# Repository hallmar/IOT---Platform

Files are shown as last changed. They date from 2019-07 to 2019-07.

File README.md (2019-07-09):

# Modular IOT Platform
Commissioned a modular IOT Platform for teaching purposes. There's a basic program in the 'Software' folder which is simply an IO test for the buttons and a test for the OLED.

Mouser Cart: https://www.mouser.com/ProjectManager/ProjectDetail.aspx?AccessID=9a8a02e45e

## Designed With

* Eagle CAD
* Arduino IDE

## Versioning
* 1.0 - [Hardware] Original hardware made
* 1.0 - [Software] Original 'basic' software written
## Authors

* **Hallmar Gauti Halldórsson**
* **Markus Pfeil**

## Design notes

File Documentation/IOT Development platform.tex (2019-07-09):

%TEMPLATE FILE
\documentclass{article}
\usepackage{graphicx} 
\usepackage{mathtools}
\usepackage{subcaption}
\usepackage[utf8x]{inputenc}
\usepackage{listings}
\usepackage{siunitx}
\usepackage{pdfpages}
\usepackage{pdflscape}
\usepackage{float}
\usepackage{xcolor}

\graphicspath{ {images/} }
\usepackage[obeyspaces]{url}
%\lstset{inputpath=C:/Users/Public/eclipse_workspace}
%\input{arduinoLanguage.tex}
\usepackage{color}   %May be necessary if you want to color links
\usepackage{hyperref}
\usepackage{titlesec}
\setcounter{secnumdepth}{4}

\hypersetup{
    colorlinks=true, % make the links colored
    linkcolor=blue, % color TOC links in blue
    urlcolor=red, % color URLs in red
    linktoc=all % 'all' will create links for everything in the TOC
    pdftitle={Sharelatex Example},
    bookmarks=true,
    pdfpagemode=FullScreen,
}
\hypersetup{
    colorlinks=true, % make the links colored
    linkcolor=blue, % color TOC links in blue
    urlcolor=blue, % color URLs in red
    linktoc=all % 'all' will create links for everything in the TOC
    pdftitle={Sharelatex Example},
    bookmarks=true,
    pdfpagemode=FullScreen,
    linkcolor=blue,
}

\definecolor{mGreen}{rgb}{0,0.6,0}
\definecolor{mGray}{rgb}{0.5,0.5,0.5}
\definecolor{mPurple}{rgb}{0.58,0,0.82}
\definecolor{backgroundColour}{rgb}{0.95,0.95,0.92}

\lstdefinestyle{CStyle}{
    %backgroundcolor=\color{backgroundColour},   
    commentstyle=\color{mGreen},
    keywordstyle=\color{magenta},
    numberstyle=\tiny\color{mGray},
    stringstyle=\color{mPurple},
    basicstyle=\footnotesize,
    breakatwhitespace=false,         
    breaklines=true,                 
    captionpos=b,                    
    keepspaces=true,                 
    numbers=left,                    
    numbersep=5pt,                  
    showspaces=false,                
    showstringspaces=false,
    showtabs=false,                  
    tabsize=2,
    language=C
}

\urlstyle{same}
\begin{document}
	\pagenumbering{gobble}
	\begin{titlepage}
		\centering
		\title{IOT Development platform \\ User manual \line(1,0){300}}
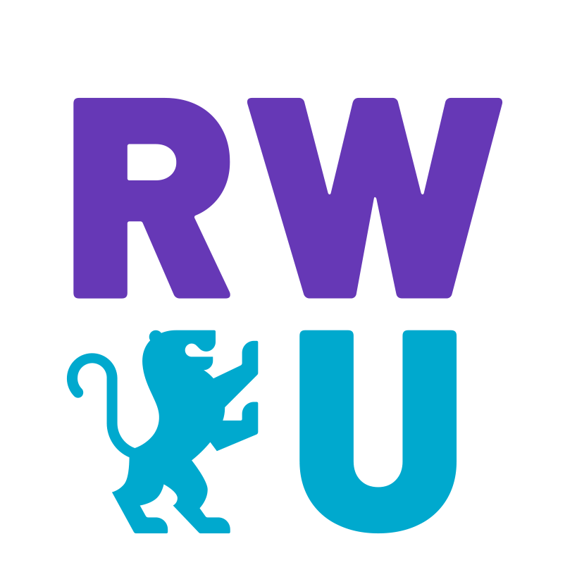
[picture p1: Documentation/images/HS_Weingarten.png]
		\date{25.06.2019 \\  \\  }
		\author{\Large Hallmar Gauti Halldórsson\\ {Matrikel: 29404} \\ 
		\\ \Large Ravensburg Weingarten Universität } %author og fleirri upplysinga
	\end{titlepage}
	\maketitle
	\newpage
	\tableofcontents
	\newpage
	\pagenumbering{arabic}

\section{Abstract}
This the documentation for an Open-Source IOT development platform that is modular in nature. It is built to have one essential part and two parts that are flexible in nature. The essential part is the Power Supply board which uses a 3.7V LIPO battery to power the whole system through a vertical pin bus. 
The Power supply board can also charge the battery and has a Buck-Boost converter to get an additional 5V voltage line out of the 3.3V voltage line that is already regulated. 
\newline\newline
Then as of now there is the Microcontroller board which has a Feather Wi-Fi development platform from Adafruit and a 2 row 90° angled header that functions as a breakout for all of the pins of the Microcontroller as well as the 5V and 3.3V power supplies with some current limiting. 
\newline\newline
And finally there is the top most board which has an OLED that is controlled via I2C, three pushbuttons and a rotary encoder with a momentary switch. This is all connected to the Feather Microcontroller. 
\newline\newline
In the following document you will find the schematics, BOM's and important tips for assembling the platform. 
 %\ref{fig: pinout}.
 \section{Tips for assembling}
 
{\color{red} Take great care when soldering the small components labeled `U', they have to be oriented correctly. There is a small dot on the component which should line up with the dot on the silkscreen. If you cannot see it then use a magnifying glass}
\newline\newline
 There are a couple things to be aware of when assembling this platform, mainly because of the Vertical Bus system that it has.
It's simply some 2.54mm pitch header pins that connect the boards together, but soldering those pins correctly so that the boards fit together can be a bit tricky. 
The best way that I have found is to simply put all of the headers on the boards without soldering, screwing them all together(or atleast the first two boards) with the hex-standoffs, make sure that the headers are flush with their respected PCB and then solder the headers while the whole assembly is screwed together. Then you will get a perfectly vertical alignment of all the header pins. 
 \newpage
But before that you naturally have to solder the components, it is best to do it from the lowest component in size; Resistors, non-polarized capacitors, components labeled `U' then finally the USB connector and polarized capacitors. 
\newline\newline
To secure the battery I used some simple double sided tape. So far this has secured it pretty well. 
{\color{red} Be also aware that you need to solder two pads on the OLED screen before soldering it to the board because we are using it in I2C mode}, see the picture below. \\\\ If you want to use the frontpanel as is depicted in the section \hyperref[fig:HIDpic]{pictures for the HID Board.} then it's best to solder the header pins to the OLED, put the OLED in the PCB but DON'T SOLDER, then mount the frontpanel, put the device on it's front(frontpanel downwards), check if the OLED is straight and THEN you solder it to the PCB. The pins might be short so they might not go to the other side but just solder the pins on the other side of the PCB. You can see how I did it in the \hyperref[fig:HIDpic]{pictures for the HID Board.}
  \begin{figure}[H]
  	\centering
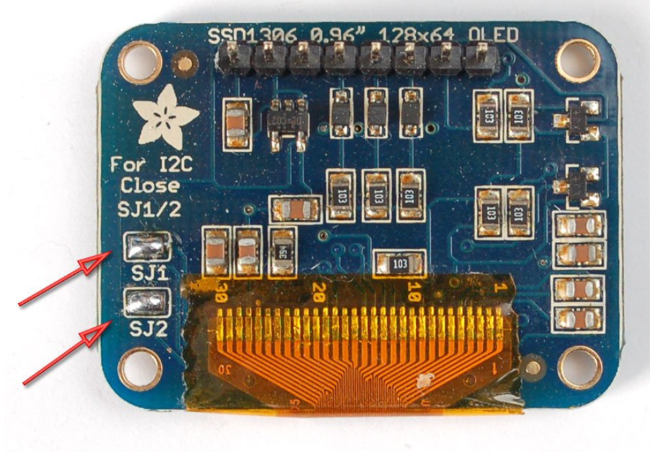
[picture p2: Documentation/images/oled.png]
  	
  	\caption{I2C config for OLED}
 	 \label{fig:oled}
\end{figure}
%%%%%%%%%%%%%%%%%%%%
 \section{Vertical Bus}
 Here is a simple depiction of the vertical bus with the current versions of the Microcontroller board and HID board.
  \begin{figure}[H]
  	\centering
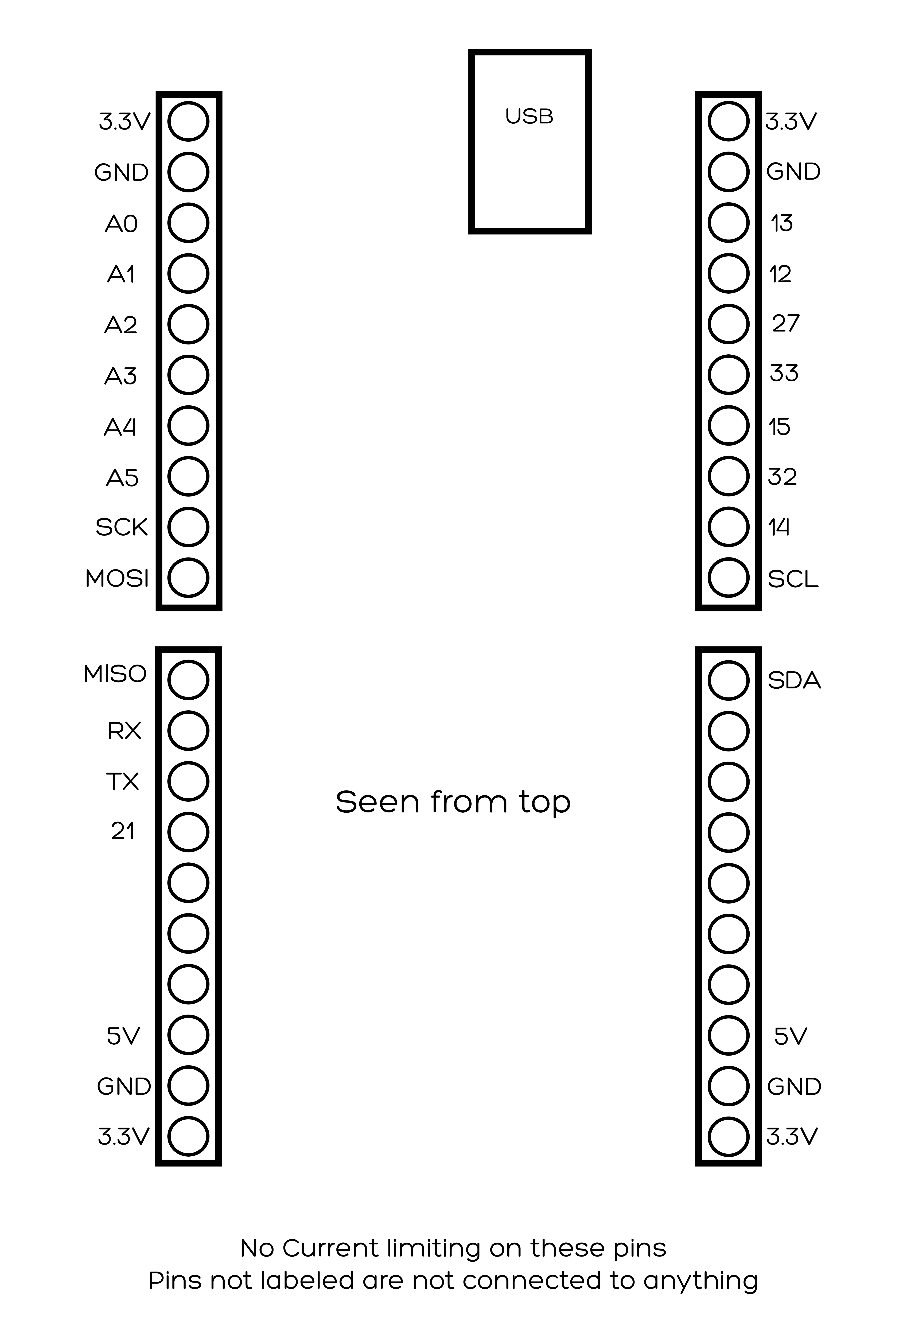
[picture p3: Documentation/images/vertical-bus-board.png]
  	
  	\caption{Pinout for Vertical bus-board}
 	 \label{fig:vertical}
\end{figure}
\newpage
%%%%%%%%%%%%%%%%%%%%%
 \section{Battery/PSU PCB}
 This is the most important PCB since it powers the whole system and charges the battery. A Green LED indicates that power is ON and a red LED indicates that the battery is charging. The battery can charge while you use the system because there is a simple mosfet circuit that will disconnect the battery to the rest of the circuit except the battery charging part. \newline\newline
 The circuit also has a 3.3V to 5V buck-boost converter to be able to have 5V for prototyping purposes or for anything that requires 5V in the system. As of now everything runs on the 3.3V power supply. 
\newline
 Please take note that the Buck-Boost converter chip can only supply 100mA MAX. If you go above that or near it you might risk damage to the chip. 
 
 \subsection{BOM}
  \begin{center}
    \begin{tabular}{ |m{2em}|m{7em}|m{7em}|m{7em}|}
    \hline
	 \multicolumn{4}{|c|}{\textbf{Power Supply}} \\
	 \hline
       \textbf{Part} & \textbf{Value} & \textbf{Type} & \textbf{Package} \\ \hline
	C1 & 10$\mu$  & Electrolytic Capacitor & 0810 \\ \hline
	C2 & 10$\mu$  & Electrolytic Capacitor & 0810 \\ \hline
	C3 & 10$\mu$  & Electrolytic Capacitor & 0810 \\ \hline
	C4 & 100n & Capacitor & 1206 \\ \hline
	C5 & 10$\mu$  & Electrolytic Capacitor & 0810 \\ \hline
	C6 & 100n & Capacitor & 1206 \\ \hline
	C7 & 10$\mu$ & Electrolytic Capacitor & 0810 \\ \hline
	C8 & 10$\mu$ & Electrolytic Capacitor & 0810 \\ \hline
	
	D1 & MBRS130LT3 & Schottky Diode & SMB \\ \hline
	L1 & 10$\mu$ & Inductor & L3216C \\ \hline
	LED1 & RED  & LED & 3mm \\ \hline
	LED2 & GREEN & LED & 3mm \\ \hline
	Q1 & FDN360P & Transistor & SSOT-3\\ \hline
	
	R1 & 1k & Resistor & 1206 \\ \hline
	R2 & 100k & Resistor & 1206 \\ \hline
	R3 & 1k & Resistor & 1206 \\ \hline
	R4 & 100k & Resistor & 1206 \\ \hline
	R5 & 1k & Resistor & 1206 \\ \hline
	R6 & 220k & Resistor & 1206 \\ \hline
	R7 & 1M & Resistor & 1206 \\ \hline
	R8 & 100k & Resistor & 1206 \\ \hline
	R9 & 309k & Resistor & 1206 \\ \hline
	
	S1 & EG1213 & E-Switch & EG1213 \\ \hline
	U1 & AP2112K-3.3TRG1 & CMOS LDO & SOT-25-5 \\ \hline
	U2 & MCP73831 & LIPO Charger & SOT-23 \\ \hline
	U3 & MAX1834 & Buck-Boost Converter & SOT-23-6 \\ \hline
	X1 & PN61729-S & USB-B connector & PN61729-S \\ \hline
	SV1 & 10 pin & Female header & 2.54mm Pitch \\ \hline
	SV2 & 10 pin & Female header & 2.54mm Pitch \\ \hline
	SV3 & 10 pin & Female header & 2.54mm Pitch \\ \hline
	SV4 & 10 pin & Female header & 2.54mm Pitch \\ \hline
	CN1 & JST-2pin & 2 Pin connector & Adafruit \\ \hline
	
	Bat & 1200mA 3.7V & LIPO battery & Adafruit(see links section) \\ \hline
    \end{tabular}
     \end{center}
     \subsection{Placement}
         \begin{figure}[H]
  	\centering
  	
  	\caption{Placement for PSU board}
 	 \label{fig:place2}
\end{figure}

  \subsection{Schematic}
     \begin{figure}[H]
  	\centering
  	
  	\caption{Schematic for PSU board}
 	 \label{fig:schematic2}
\end{figure}
 \subsection{Pictures}
 As can be seen on the picture there is an extra capacitor soldered where the arrow is pointing. This is C8, in this prototype I forgot to put it there which resulted in the 5V to only have an RMS value of around 4.3V. With this C8 the 4.3V jumped up to 5V, as it should be.
  \begin{figure}[H]
  	\centering
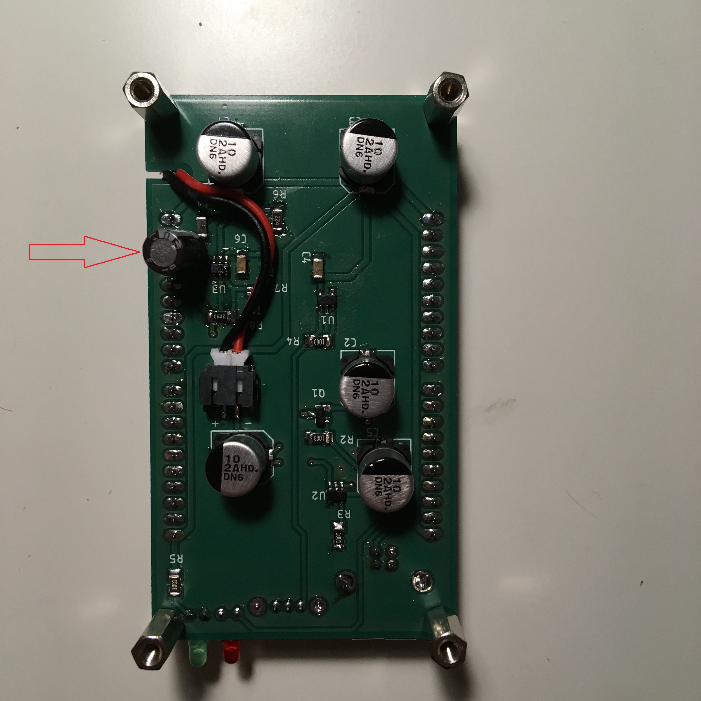
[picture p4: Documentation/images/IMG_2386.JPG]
  	
  	\caption{Photo of the prototype PCB}
 	 \label{fig: pcb21}
\end{figure}
  \begin{figure}[H]
  	\centering
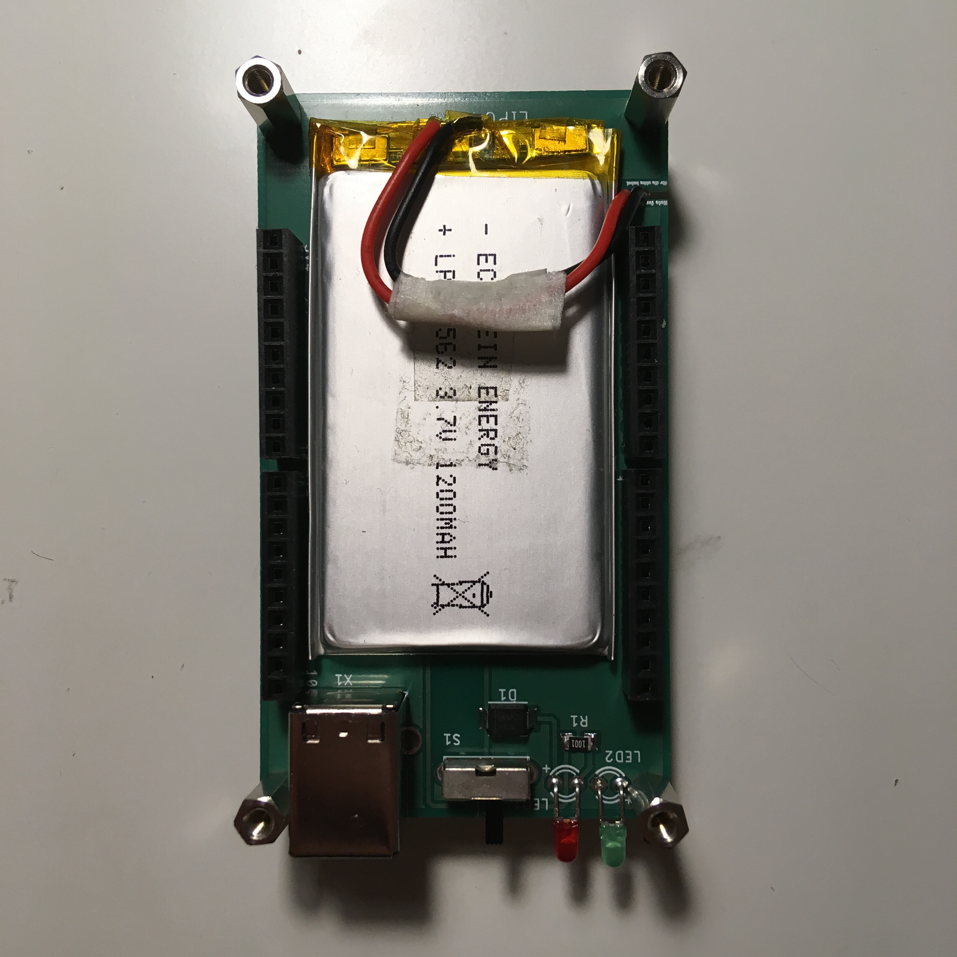
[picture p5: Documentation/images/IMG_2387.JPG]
  	
  	\caption{Photo of the prototype PCB}
 	 \label{fig: pcb22t}
\end{figure}
 \newpage
 %%%%%%%%%%%%%%%%%%%%%%%%%%%5
 \section{Microcontroller PCB}
 This is the heart of the whole system, here is the Microcontroller that handles everything.
This board also has a  \hyperref[fig: pinout]{prototype header} that can be connected to a breadboard for prototyping all sorts of stuff.
This header has +5V and +3.3V that are limited to 100mA and 150mA respectively.
  \subsection{BOM}
 \begin{center}
    \begin{tabular}{ |m{2em}|m{7em}|m{7em}|m{7em}|}
    \hline
	 \multicolumn{4}{|c|}{\textbf{Microcontroller}} \\
	 \hline
       \textbf{Part} & \textbf{Value} & \textbf{Type} & \textbf{Package} \\ \hline
	R1 & 1k & Resistor & 1206 \\ \hline
	R2 & 1.5k & Resistor & 1206 \\ \hline
	U1 & ESP32-Feather & Microcontroller & -  \\ \hline
	U2 & MIC2009A & Current limiter & SOT-23-6 \\ \hline
	U3 & MIC2009A & Current limiter & SOT-23-6 \\ \hline
	SV1 & 10 pin & Stackable header & Sparkfun: PRT-11376 \\ \hline
	SV2 & 10 pin & Stackable header & Sparkfun: PRT-11376 \\ \hline
	SV3 & 10 pin & Stackable header & Sparkfun: PRT-11376 \\ \hline
	SV4 & 10 pin & Stackable header & Sparkfun: PRT-11376 \\ \hline
	JP3  & 24 pin & 2 row 90° female header & 2.54mm Pitch \\ \hline
    \end{tabular}
     \end{center}
 \newpage
 
      \subsection{Placement}
         \begin{figure}[H]
  	\centering
  	
  	\caption{Placement for Microcontroller board}
 	 \label{fig:place3}
\end{figure}

  \subsection{Schematic}
   \begin{figure}[H]
  	\centering
  	
  	\caption{Schematic for Microcontroller board}
 	 \label{fig:schematic3}
\end{figure}
\newpage

 \subsection{Pictures}
 \begin{figure}[H]
  	\centering
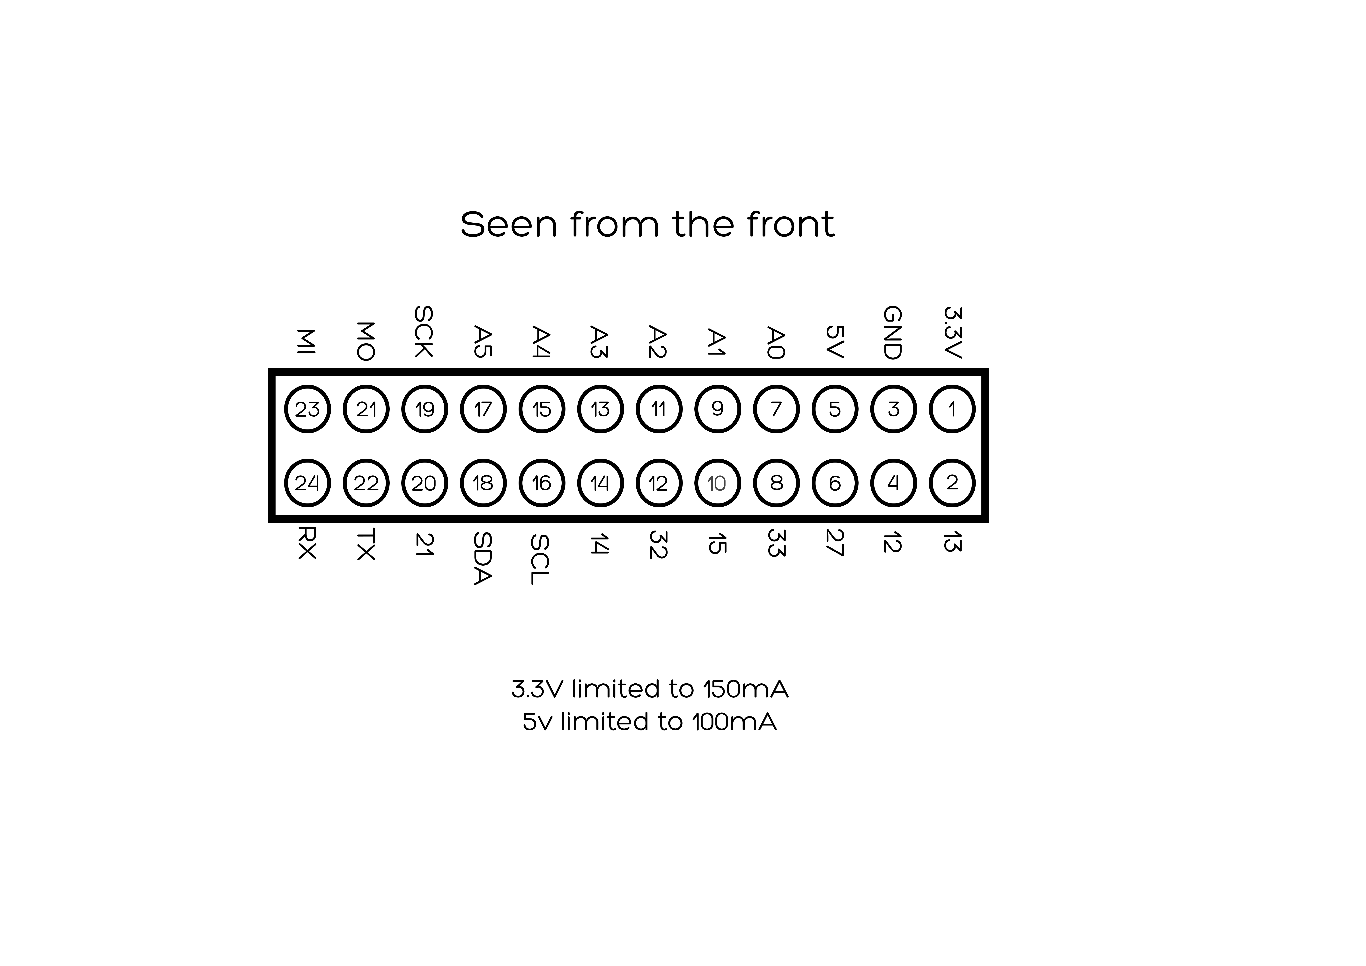
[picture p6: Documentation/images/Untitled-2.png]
  	
  	\caption{Pinout for Prototyping header}
 	 \label{fig: pinout}
\end{figure}
 \begin{figure}[H]
  	\centering
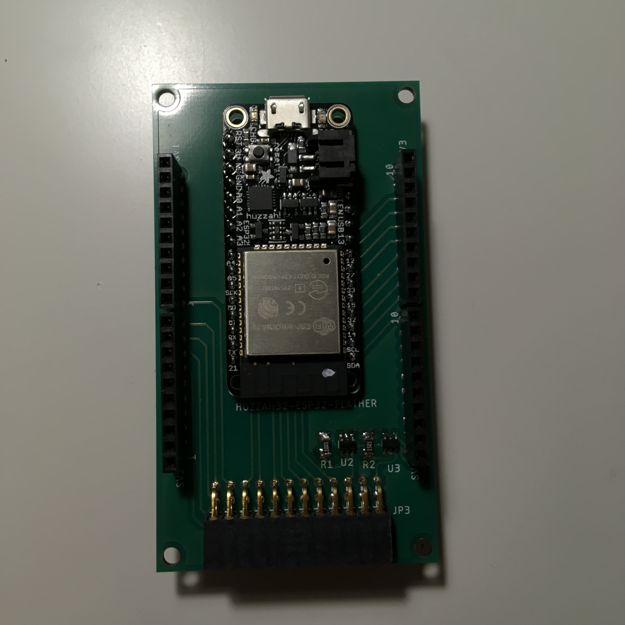
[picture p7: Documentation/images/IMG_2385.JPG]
  	
  	\caption{PCB prototype}
 	 \label{fig: pcb3}
\end{figure}
\newpage
%%%%%%%%%%%%%%%%%%%%%%%%%%%%%5
\section{HID PCB}
This is the Human Interface Device PCB which has 3 switches, a rotary encoder(with a switch) and an OLED. 
This is all connected to the Microcontroller board. You can see to what pins each component is connected to by looking at the  \hyperref[fig:schematic4]{schematic.}

 \subsection{BOM}
  \begin{center}
    \begin{tabular}{ |m{2em}|m{7em}|m{7em}|m{7em}|}
    \hline
	 \multicolumn{4}{|c|}{\textbf{HID}} \\
	 \hline
       \textbf{Part} & \textbf{Value} & \textbf{Type} & \textbf{Package} \\ \hline
      C1 & 10n & Capacitor & 1206 \\ \hline
      C2 & 10n & Capacitor & 1206 \\ \hline
	R1 & 10k & Resistor & 1206 \\ \hline
	R2 & 10k & Resistor & 1206 \\ \hline
	R3 & 10k & Resistor & 1206 \\ \hline
	R4 & 10k & Resistor & 1206 \\ \hline
	R5 & 10k & Resistor & 1206 \\ \hline
	R6 & 10k & Resistor & 1206 \\ \hline
	R7 & 10k & Resistor & 1206 \\ \hline
	R8 & 10k & Resistor & 1206 \\ \hline
	S1 & TL1105SPF250Q & Tactile Switch & - \\ \hline
	S2 & TL1105SPF250Q & Tactile Switch & -\\ \hline
	S3 & TL1105SPF250Q & Tactile Switch & -\\ \hline
	SW1 & PEC11R-4215F-S0024 & Rotary Ecnoder & - \\ \hline
	U\$1 & Adafruit: 938  & OLED screen & -  \\ \hline
	SV1 & 10 pin & Male header & 2.54mm Pitch \\ \hline
	SV2 & 10 pin & Male header & 2.54mm Pitch \\ \hline
	SV3 & 10 pin & Male header & 2.54mm Pitch \\ \hline
	SV4 & 10 pin & Male header & 2.54mm Pitch \\ \hline
	JP3  & 24 pin & 2 row 90° female header & 2.54mm Pitch \\ \hline

    \end{tabular}
     \end{center}
     
     \subsection{Placement}
         \begin{figure}[H]
  	\centering
  	
  	\caption{Placement for HID board}
 	 \label{fig:place4}
\end{figure}
 \subsection{Schematic}
    \begin{figure}[H]
  	\centering
  	
  	\caption{Schematic for HID board}
 	 \label{fig:schematic4}
\end{figure}
 \subsection{Pictures}
  \begin{figure}[H]
  	\centering
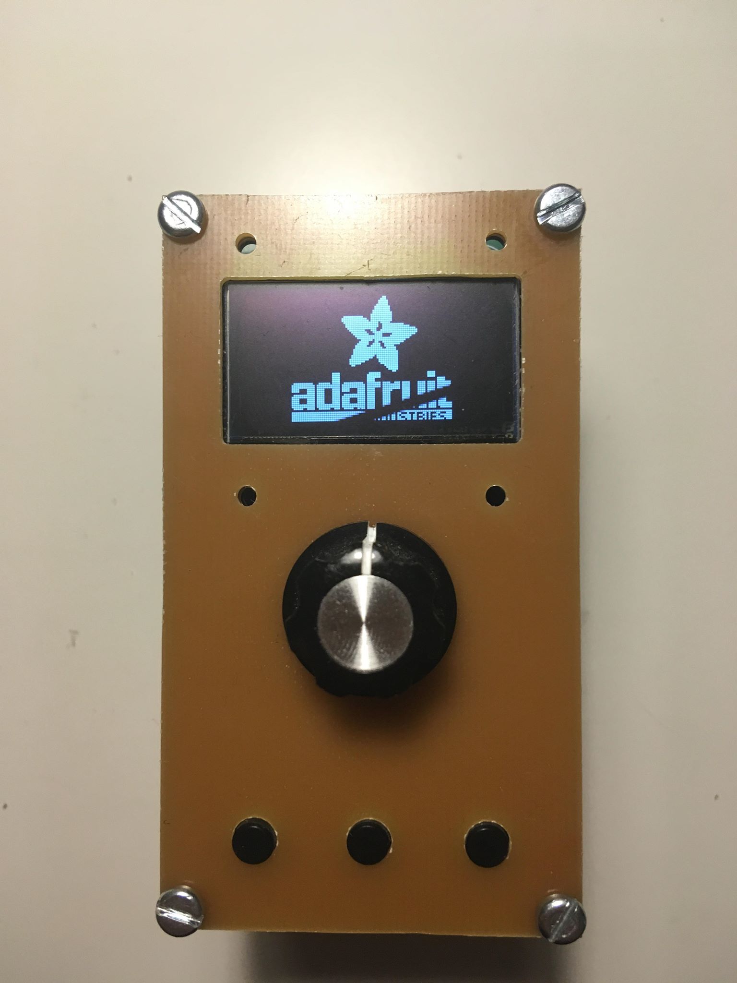
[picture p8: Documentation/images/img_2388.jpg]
  	
  	\caption{Photo of the prototype PCB}
 	 \label{fig:HIDpic}
\end{figure}
  \begin{figure}[H]
  	\centering
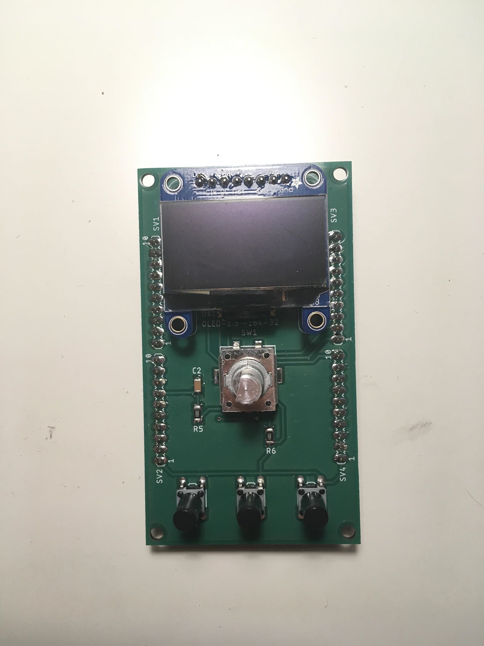
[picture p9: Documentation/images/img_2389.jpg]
  	
  	\caption{Photo of the prototype PCB}
 	 \label{fig: pcb22t}
\end{figure}

  \begin{figure}[H]
  	\centering
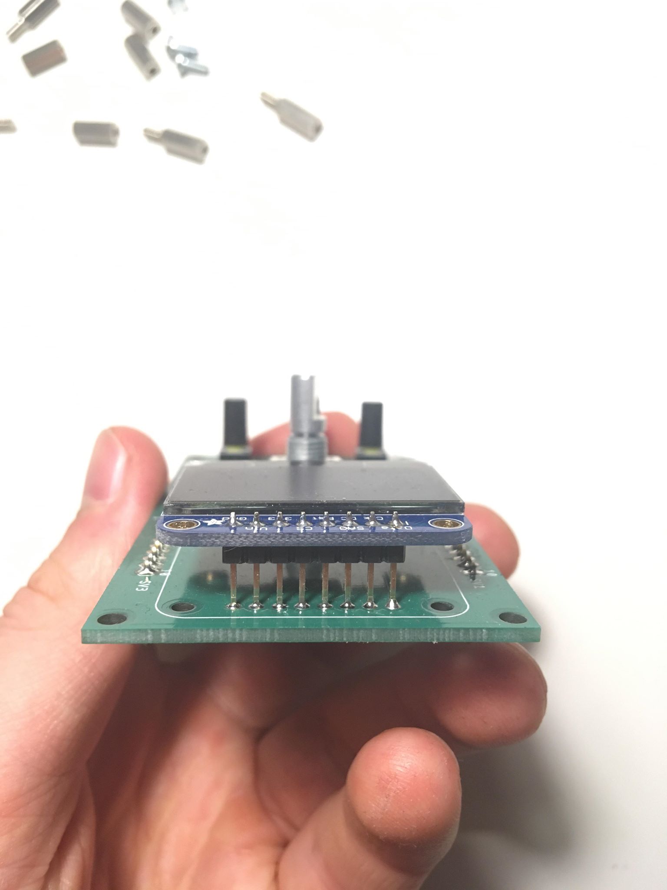
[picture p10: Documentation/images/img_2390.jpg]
  	
  	\caption{Photo of the prototype PCB}
 	 \label{fig: pcb22t}
\end{figure}

  \begin{figure}[H]
  	\centering
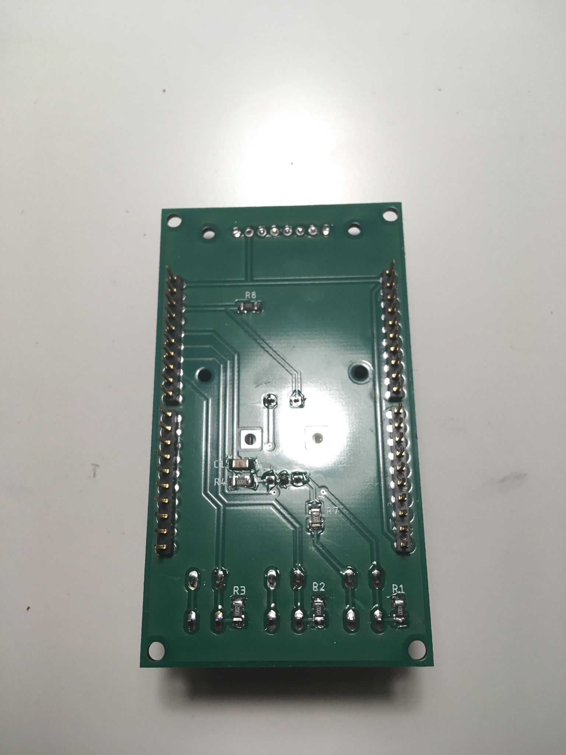
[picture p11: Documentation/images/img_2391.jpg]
  	
  	\caption{Photo of the prototype PCB}
 	 \label{fig: pcb22t}
\end{figure}
\newpage
\section{Peripherals BOM}
Here is a BOM for the peripheral stuff you need, such as screws, standoffs and switch caps. 

  \begin{center}
    \begin{tabular}{ |m{6em}|m{7em}|m{7em}|m{7em}|}
    \hline
	 \multicolumn{4}{|c|}{\textbf{Peripherals}} \\
	 \hline
       \textbf{Amount} & \textbf{Value} & \textbf{Type} & \textbf{Mouser. No} \\ \hline
	3 & 1RBLK & Cap for switches & 1RBLK \\ \hline
	8 & M3 Screw 6mm & Screw & 534-29311 \\ \hline
	12 & 11mm HEX standoff M/F & Standoff & 855-R30-3001102 \\ \hline
	4 & 11mm HEX standoff F/F & Standoff & 855-R30-1001102 \\ \hline
    \end{tabular}
     \end{center}

\section{Links}
Here are some useful (clickable) links for purchasing of the LIPO battery since it cannot be purchased from mouser and some other useful links for the Microcontroller, OLED, some libraries and ect. 
\begin{itemize}
	\item \href{https://www.adafruit.com/product/938}{OLED Display} 
	\item \href{https://learn.adafruit.com/adafruit-huzzah32-esp32-feather?view=all}{ESP32 Feather platform Information}
	\item \href{https://learn.adafruit.com/adafruit-huzzah32-esp32-feather/using-with-arduino-ide}{Using ESP32 Feather with Arduino IDE}
	\item \href{https://randomnerdtutorials.com/esp32-access-point-ap-web-server/}{Access Point Tutorial for ESP32}
	\item \href{https://randomnerdtutorials.com/esp32-web-server-arduino-ide/}{Web server Tutorial for ESP32}
	\item \href{https://github.com/ThingPulse/esp8266-oled-ssd1306}{Library for Adafruit OLED}
	\item \href{https://github.com/adafruit/Adafruit-GFX-Library}{Library for Adafruit OLED(GFX)}
	\item \href{https://www.adafruit.com/product/258}{LIPO battery on Adafruit} 
	\item 	\href{https://eckstein-shop.de/LiPo-Akku-Lithium-Ion-Polymer-Batterie-37V-1200mAh-JST-PH-Connector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}{Purchase LIPO Battery in Europe}
	\item \href{https://www.mouser.com/ProjectManager/ProjectDetail.aspx?AccessID=9a8a02e45e}{Mouser Cart}
\end{itemize}

\end{document}

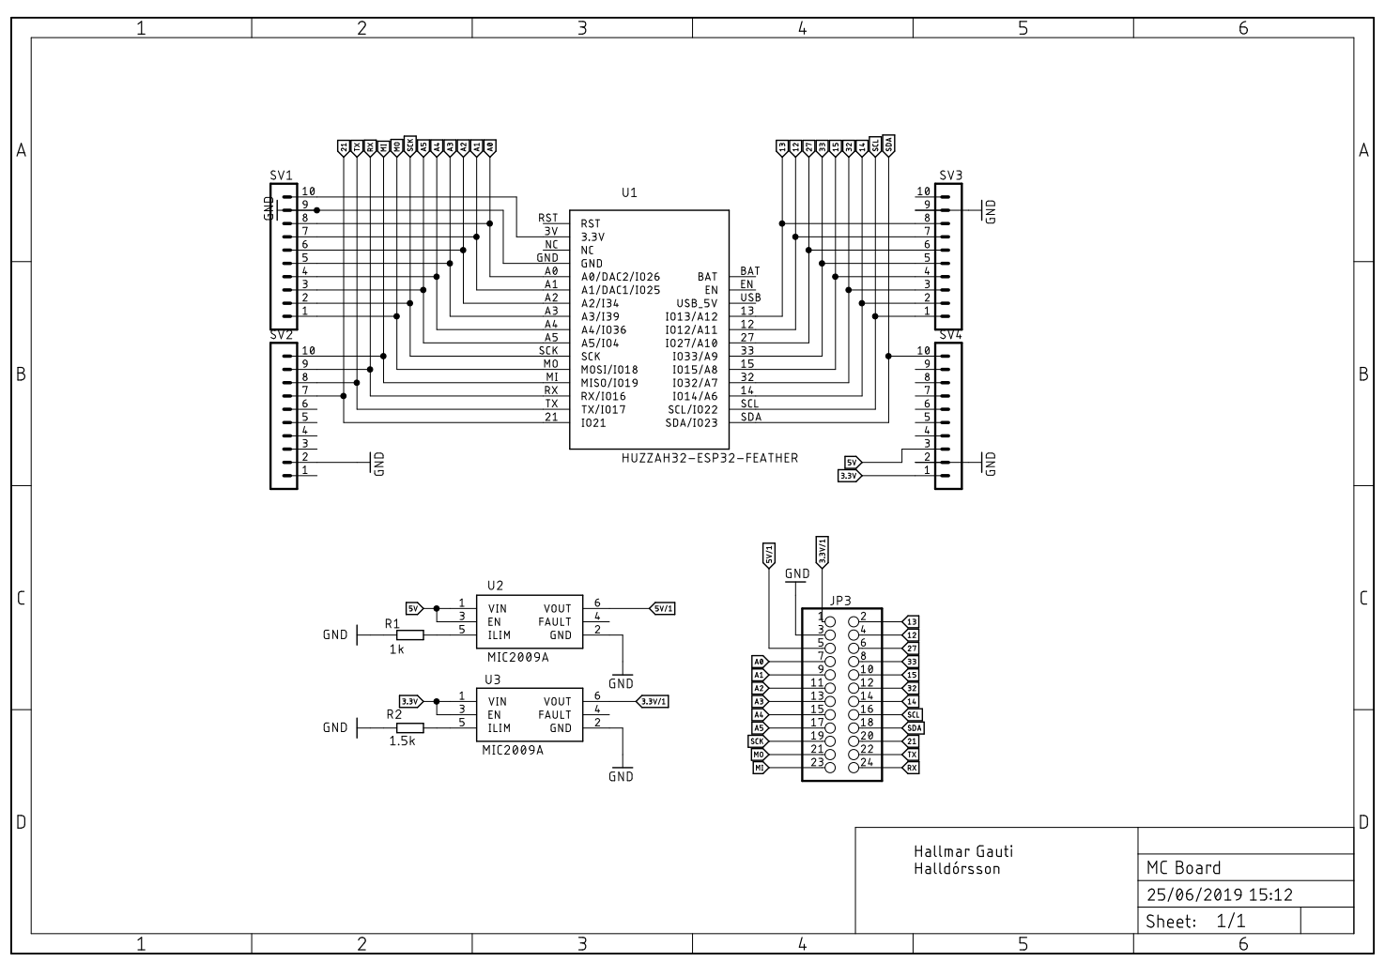
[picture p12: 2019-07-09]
Documentation/images/microcontroller.png

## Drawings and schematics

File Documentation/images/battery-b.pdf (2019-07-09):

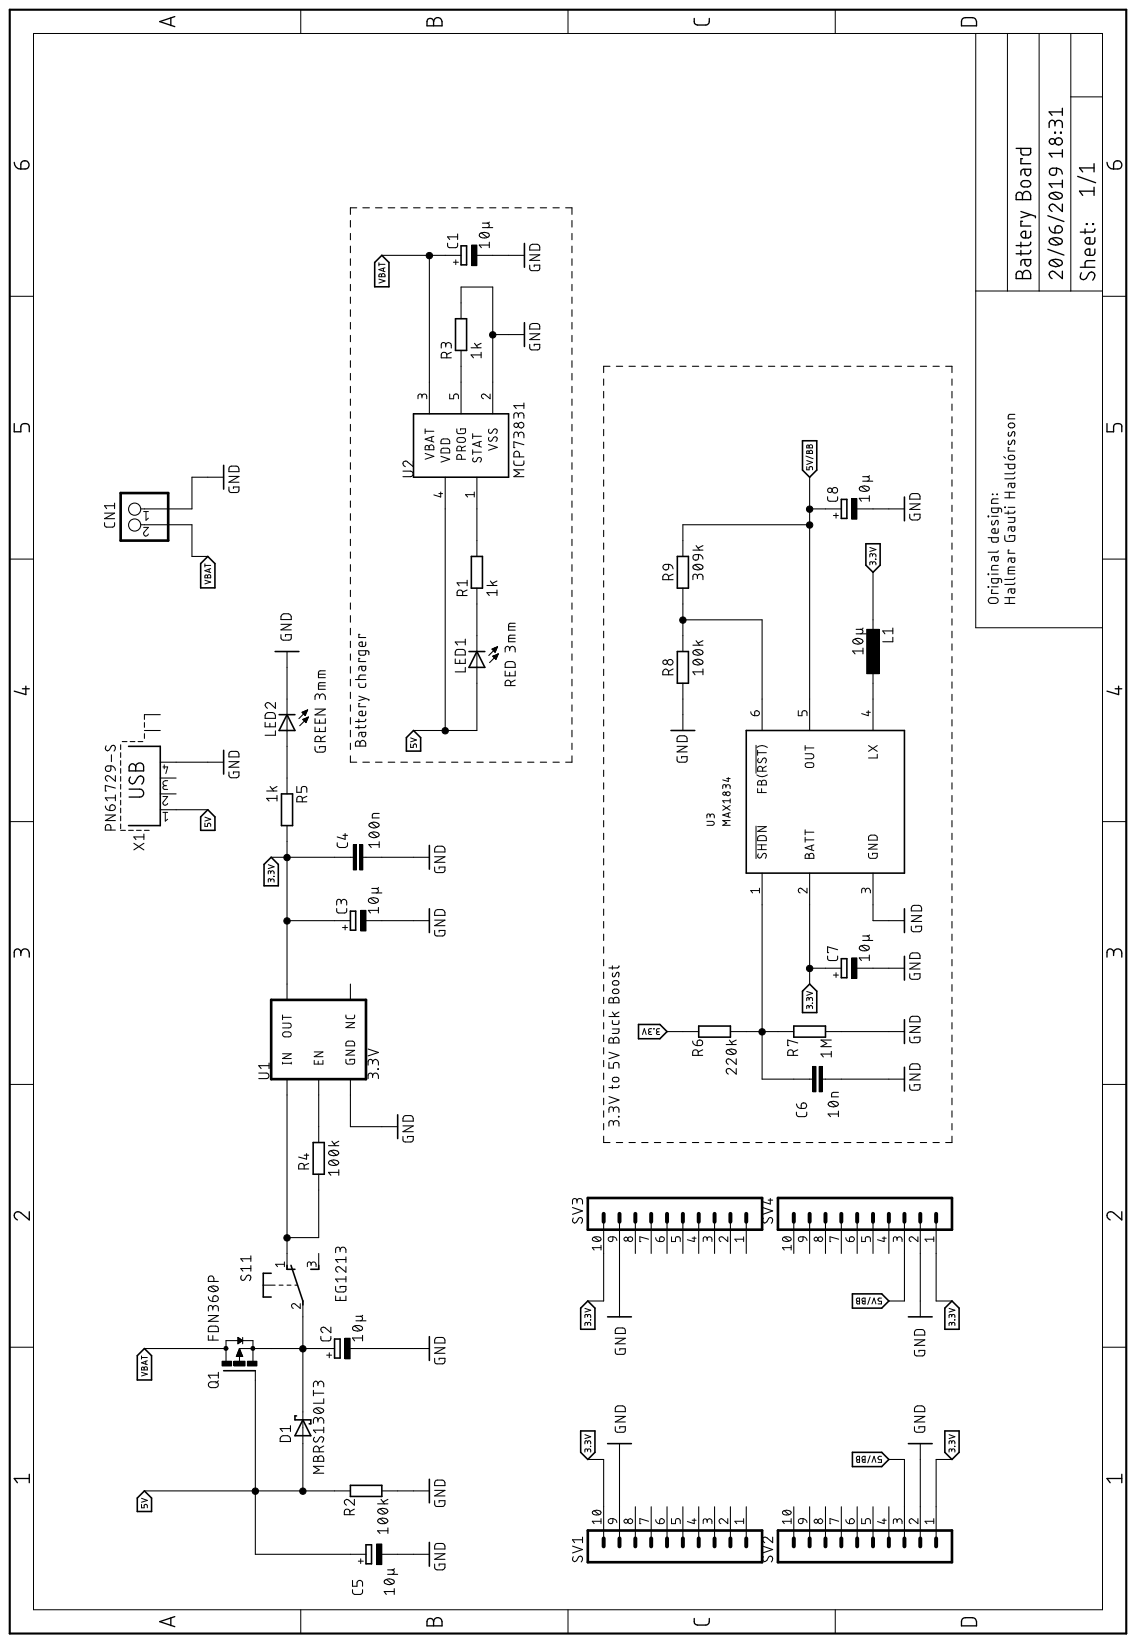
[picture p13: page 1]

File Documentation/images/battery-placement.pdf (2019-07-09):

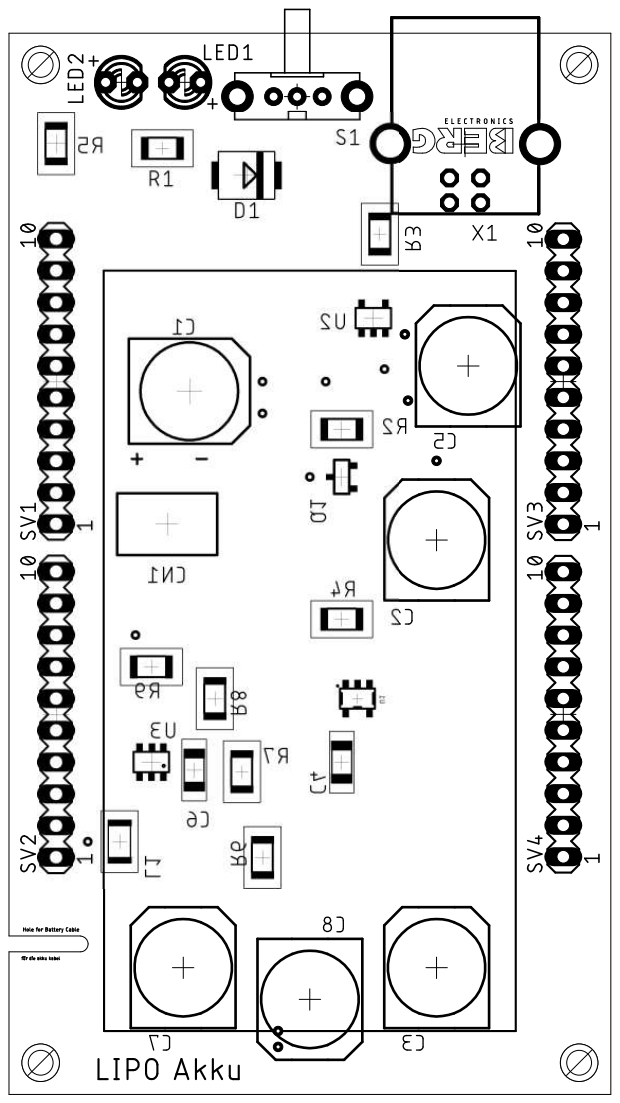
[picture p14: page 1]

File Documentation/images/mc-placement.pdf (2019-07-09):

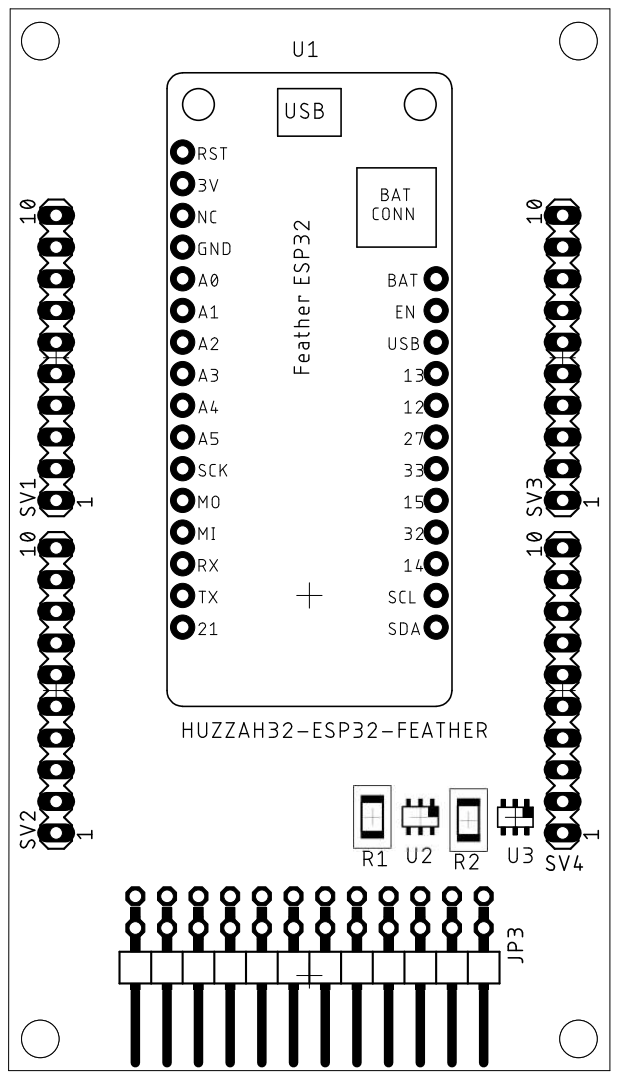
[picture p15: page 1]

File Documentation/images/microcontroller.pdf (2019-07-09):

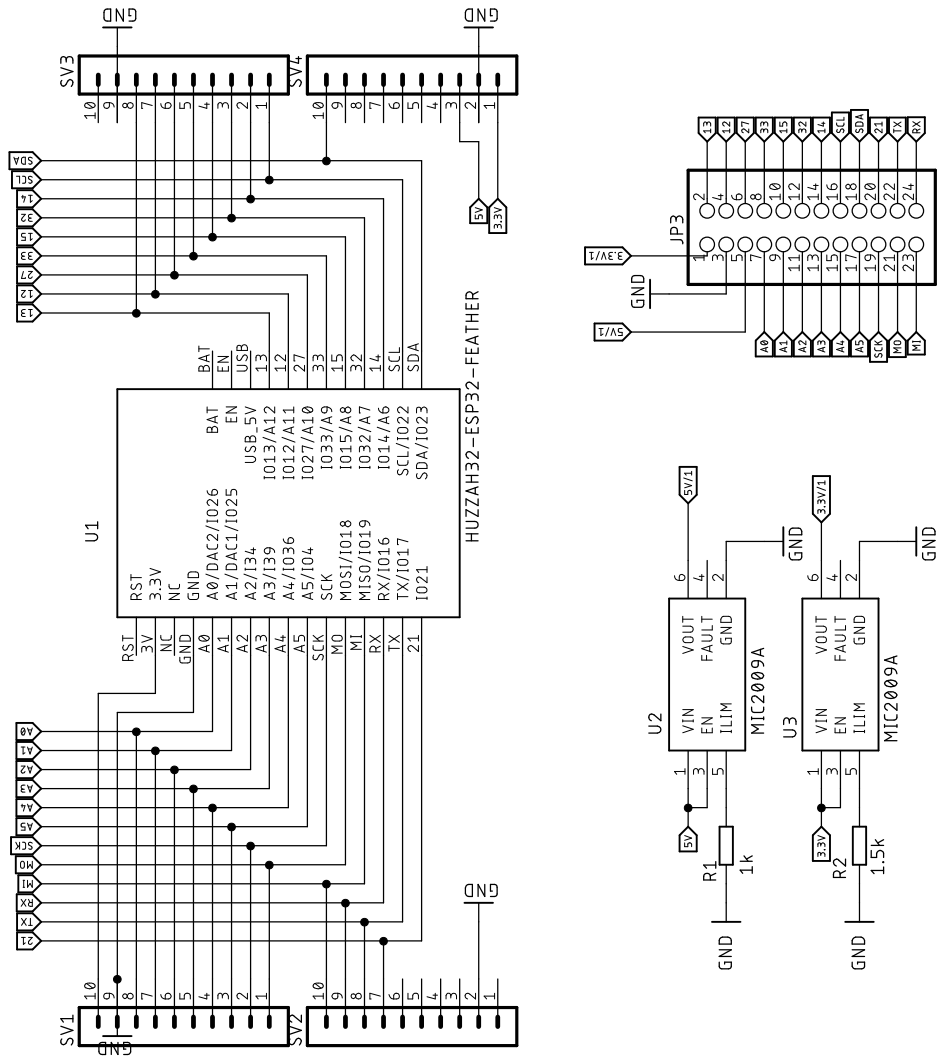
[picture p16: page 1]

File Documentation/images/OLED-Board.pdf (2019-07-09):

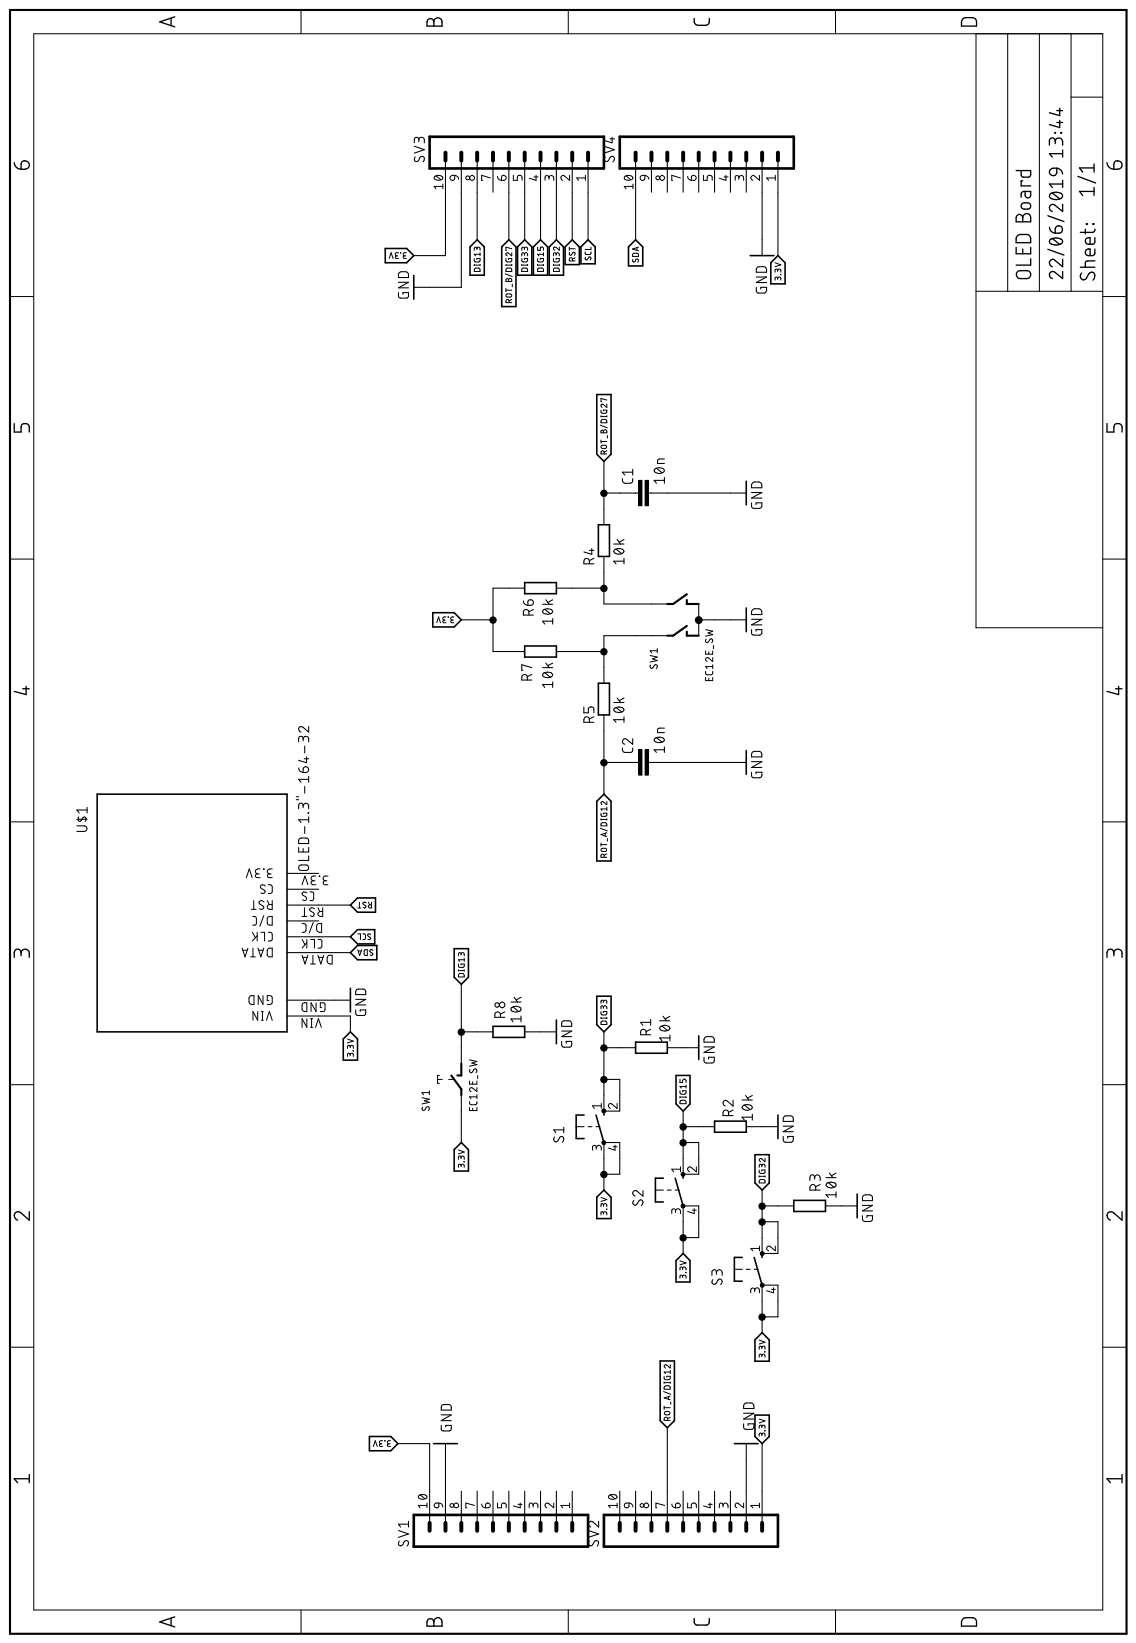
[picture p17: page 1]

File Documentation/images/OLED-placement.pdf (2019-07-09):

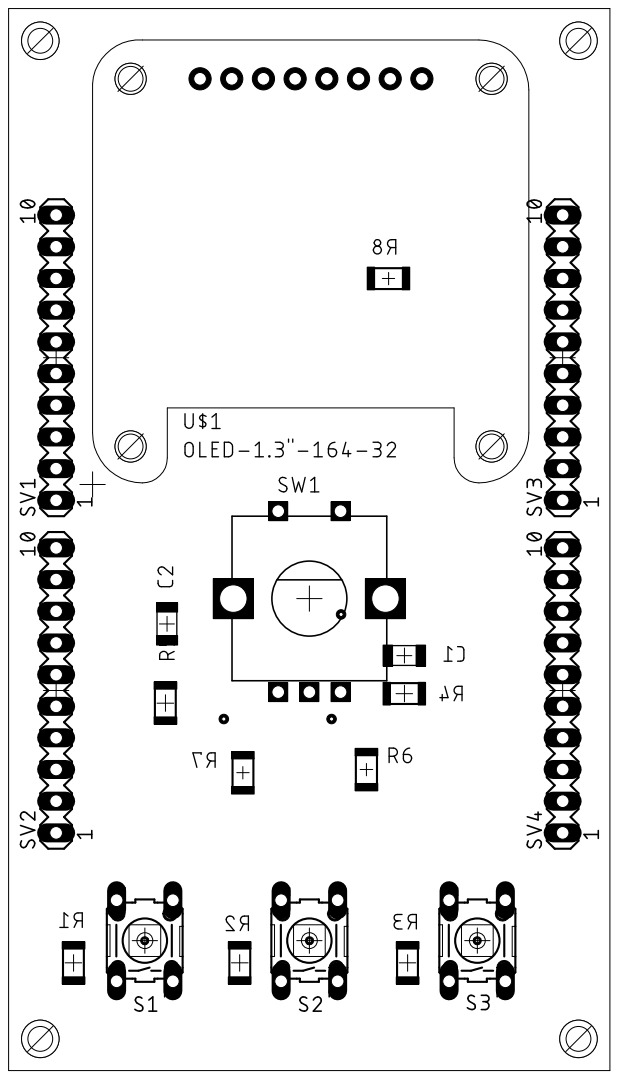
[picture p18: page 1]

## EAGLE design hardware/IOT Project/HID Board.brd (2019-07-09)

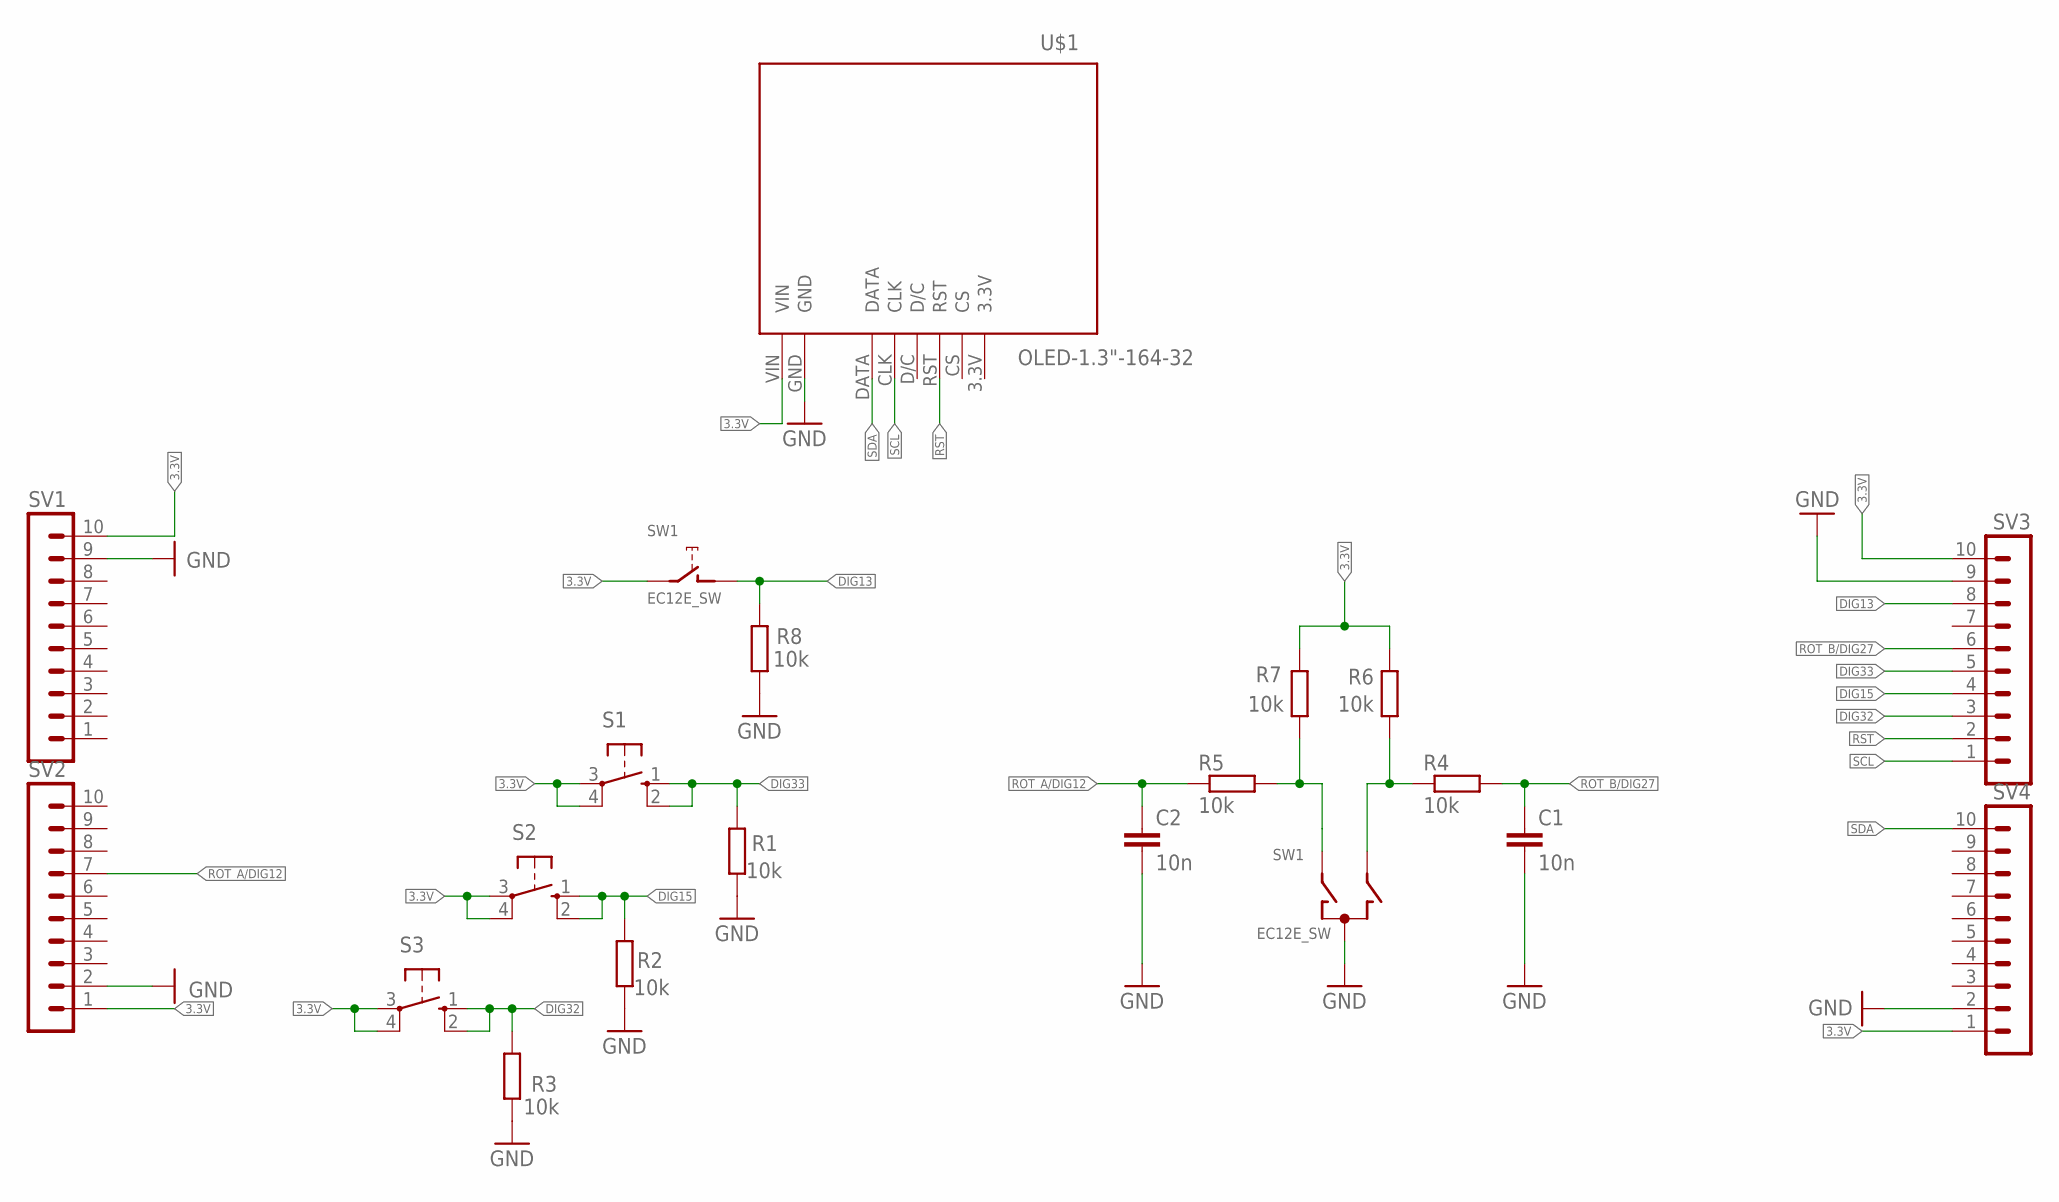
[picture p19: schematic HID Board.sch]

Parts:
C1, C2: 10n; C1206
R1, R2, R3, R4, R5, R6, R7, R8: 10k; M1206
S1, S2, S3: 10-XX; B3F-10XX
SV1, SV2, SV3, SV4: MA10-1
SW1: EC12E_SW; ALPS_EC12E_SW
U$1: OLED-1.3"-164-32

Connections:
3.3V: R6.2, R7.2, S1.3, S1.4 (P1), S2.3, S2.4 (P1), S3.3, S3.4 (P1), SV1.10, SV2.1, SV3.10, SV4.1, SW1.E (2), U$1.VIN
DIG13: R8.2, SV3.8, SW1.D (1)
DIG15: R2.2, S2.1 (S), S2.2 (S1), SV3.4
DIG32: R3.2, S3.1 (S), S3.2 (S1), SV3.3
DIG33: R1.2, S1.1 (S), S1.2 (S1), SV3.5
GND: C1.2, C2.2, R1.1, R2.1, R3.1, R8.1, SV1.9, SV2.2, SV3.9, SV4.2, SW1.C, U$1.GND
unnamed: R5.2, R7.1, SW1.A
unnamed: R4.1, R6.1, SW1.B
ROT_A/DIG12: C2.1, R5.1, SV2.7
ROT_B/DIG27: C1.1, R4.2, SV3.6
RST: SV3.2, U$1.RST
SCL: SV3.1, U$1.CLK
SDA: SV4.10, U$1.DATA

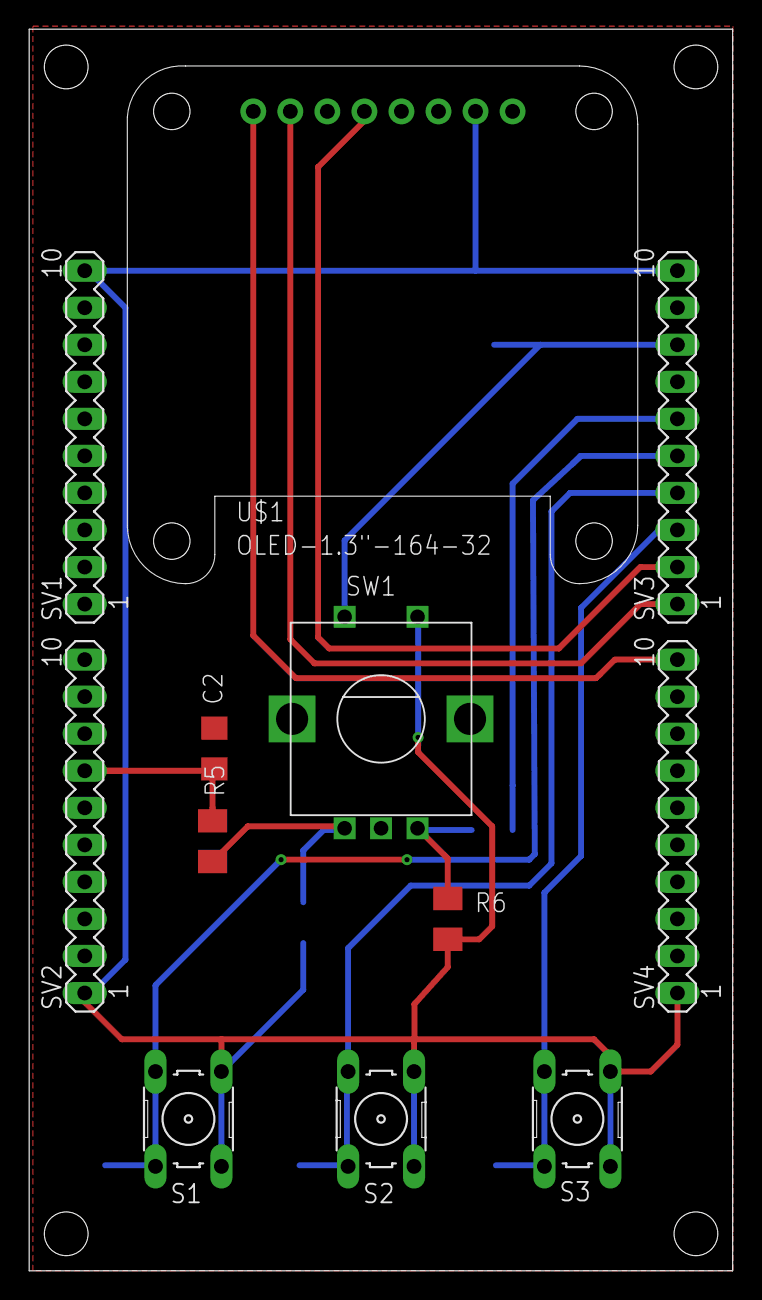
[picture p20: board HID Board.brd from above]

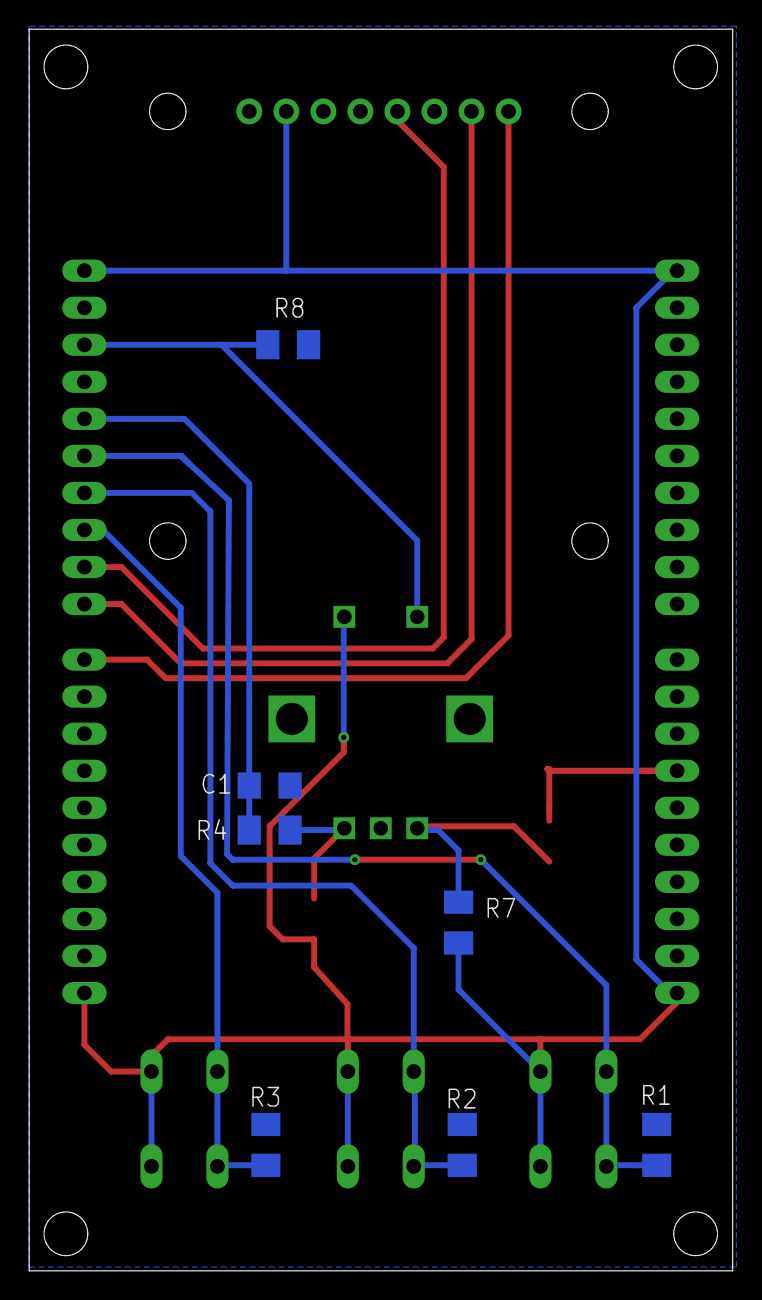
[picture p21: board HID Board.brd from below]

Board: 2 copper layers, 48.2 x 85.1 mm, 19 parts (7 on the bottom side), 13 nets.

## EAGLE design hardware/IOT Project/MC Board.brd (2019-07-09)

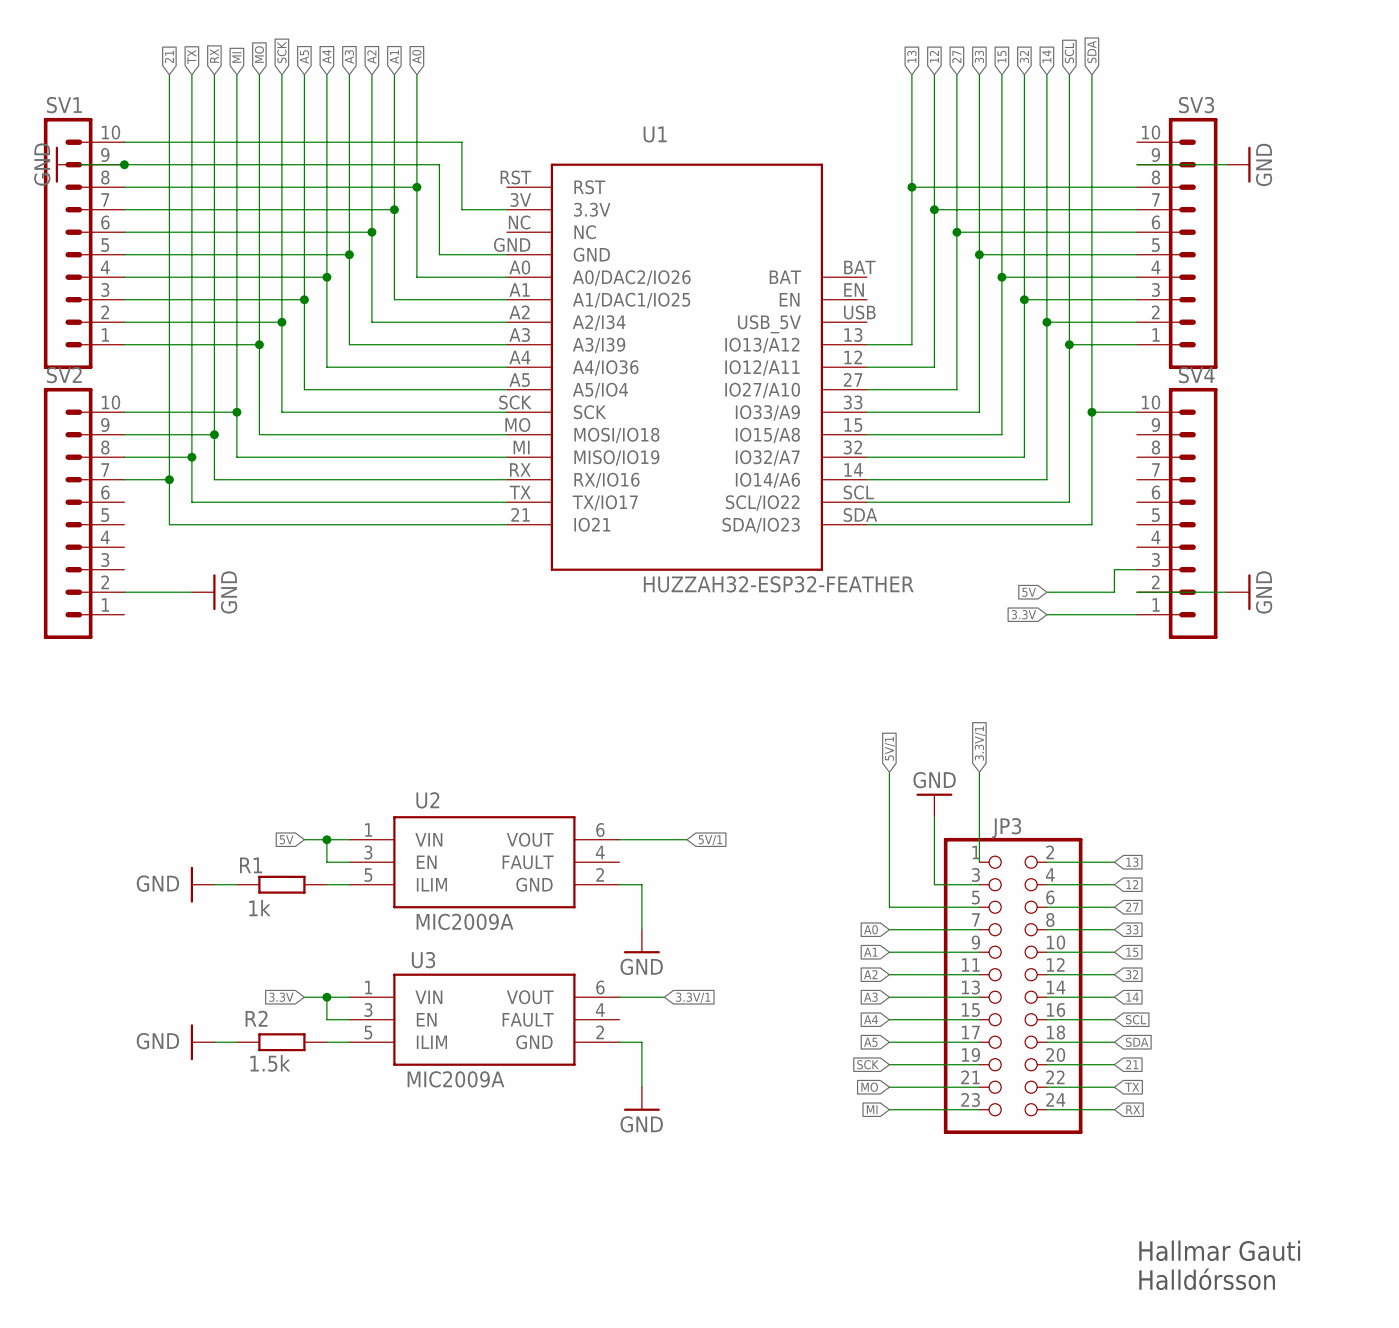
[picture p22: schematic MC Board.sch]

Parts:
JP3: PINHD-2X12/90; 2X12/90
R1: 1k; M1206
R2: 1.5k; M1206
SV1, SV2, SV3, SV4: MA10-1
U1: HUZZAH32-ESP32-FEATHER; ESP32-FEATHER
U2, U3: MIC2009A

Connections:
3.3V: SV4.1, U3.1 (VIN), U3.3 (EN)
3.3V/1: JP3.1, U3.6 (VOUT)
5V: SV4.3, U2.1 (VIN), U2.3 (EN)
5V/1: JP3.5, U2.6 (VOUT)
12: JP3.4, SV3.7, U1.12 (IO12/A11)
13: JP3.2, SV3.8, U1.13 (IO13/A12)
14: JP3.14, SV3.2, U1.14 (IO14/A6)
15: JP3.10, SV3.4, U1.15 (IO15/A8)
21: JP3.20, SV2.7, U1.21 (IO21)
27: JP3.6, SV3.6, U1.27 (IO27/A10)
32: JP3.12, SV3.3, U1.32 (IO32/A7)
33: JP3.8, SV3.5, U1.33 (IO33/A9)
A0: JP3.7, SV1.8, U1.A0 (A0/DAC2/IO26)
A1: JP3.9, SV1.7, U1.A1 (A1/DAC1/IO25)
A2: JP3.11, SV1.6, U1.A2 (A2/I34)
A3: JP3.13, SV1.5, U1.A3 (A3/I39)
A4: JP3.15, SV1.4, U1.A4 (A4/IO36)
A5: JP3.17, SV1.3, U1.A5 (A5/IO4)
GND: JP3.3, R1.2, R2.1, SV1.9, SV2.2, SV3.9, SV4.2, U1.GND, U2.2 (GND), U3.2 (GND)
MI: JP3.23, SV2.10, U1.MI (MISO/IO19)
MO: JP3.21, SV1.1, U1.MO (MOSI/IO18)
unnamed: SV1.10, U1.3V (3.3V)
unnamed: R2.2, U3.5 (ILIM)
unnamed: R1.1, U2.5 (ILIM)
RX: JP3.24, SV2.9, U1.RX (RX/IO16)
SCK: JP3.19, SV1.2, U1.SCK
SCL: JP3.16, SV3.1, U1.SCL (SCL/IO22)
SDA: JP3.18, SV4.10, U1.SDA (SDA/IO23)
TX: JP3.22, SV2.8, U1.TX (TX/IO17)

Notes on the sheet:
Hallmar Gauti Halldórsson

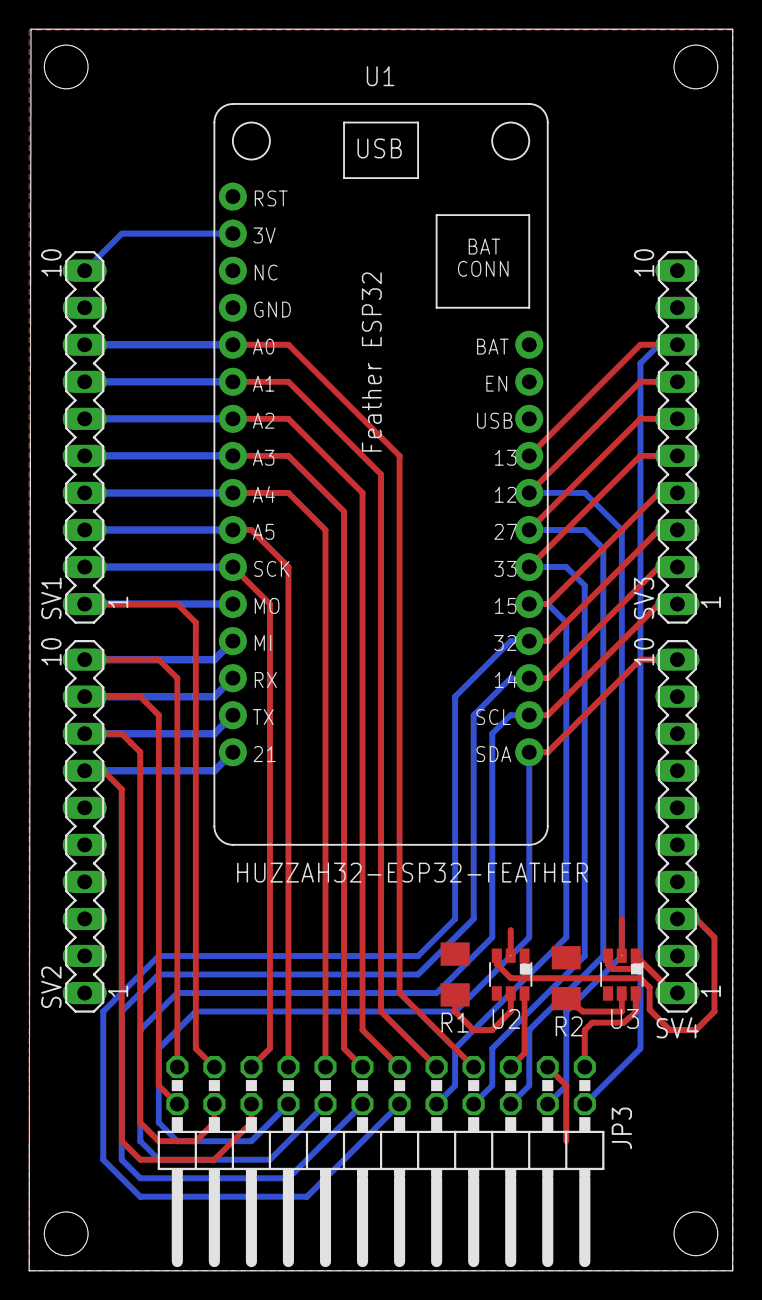
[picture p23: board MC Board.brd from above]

Board: 2 copper layers, 48.2 x 85.1 mm, 10 parts (0 on the bottom side), 29 nets.

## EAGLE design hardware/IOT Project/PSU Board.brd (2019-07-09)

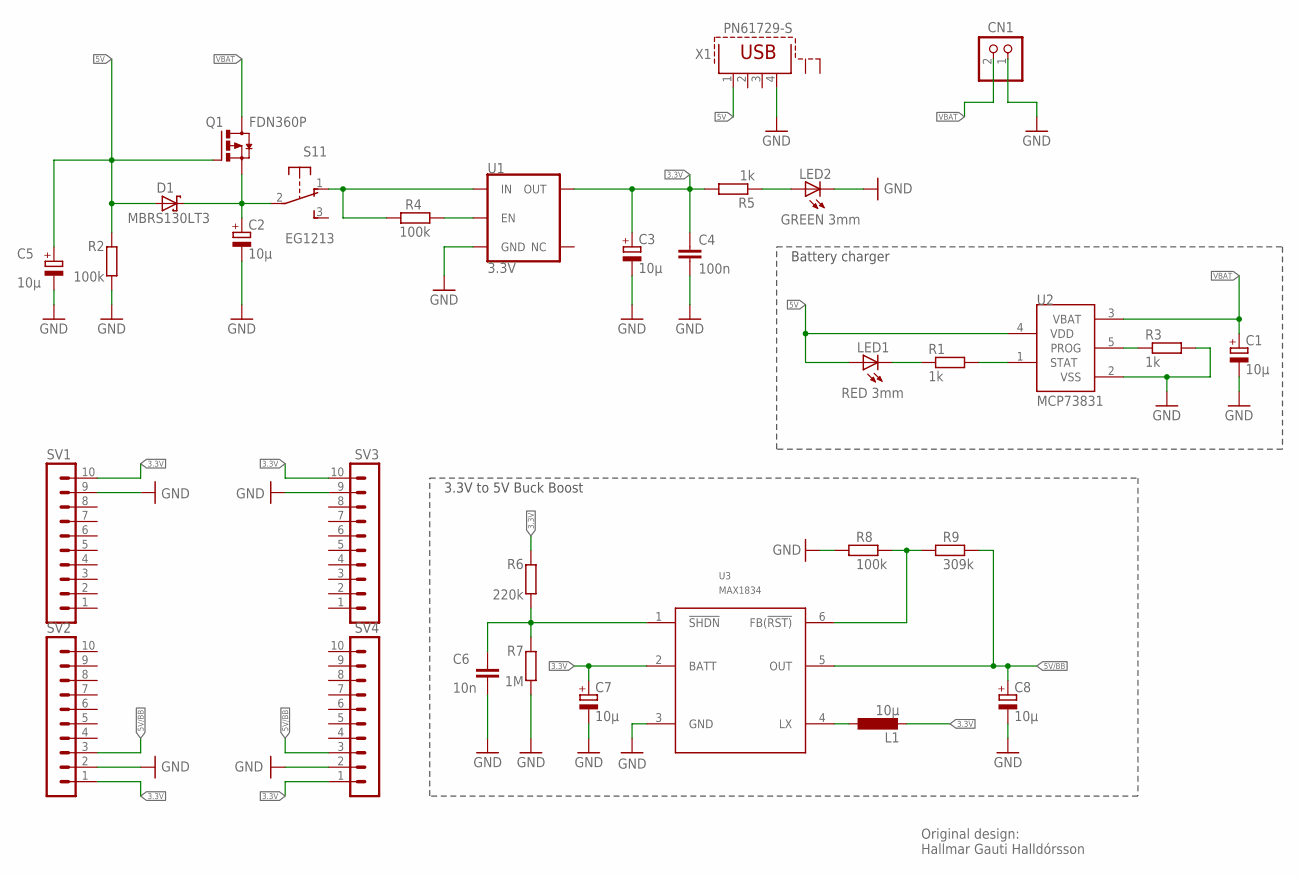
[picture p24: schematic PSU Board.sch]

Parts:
C1, C2, C3, C5, C7, C8: 10µ; 140CLH-0810
C4: 100n; C1206
C6: 10n; C1206
CN1: JST_2PIN-SMT; JST-PH-2-SMT
D1: MBRS130LT3; SMB
L1: 10µ; L3216C
LED1: RED 3mm; LED3MM
LED2: GREEN 3mm; LED3MM
Q1: FDN360P; SUPER-SOT3
R1, R3, R5: 1k; M1206
R2, R4, R8: 100k; M1206
R6: 220k; M1206
R7: 1M; M1206
R9: 309k; M1206
S1: EG1213
SV1, SV2, SV3, SV4: MA10-1
U1: 3.3V; SOT23-5
U2: MCP73831; SOT23-5L
U3: MAX1834; SOT23-6
X1: PN61729-S

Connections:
3.3V: C3.+, C4.1, C7.+, L1.2, R5.2, R6.2, SV1.10, SV2.1, SV3.10, SV4.1, U1.5 (OUT), U3.2 (BATT)
5V: C5.+, D1.A, LED1.A, Q1.1 (G), R2.2, U2.4 (VDD), X1.1
5V/BB: C8.+, R9.1, SV2.3, SV4.3, U3.5 (OUT)
GND: C1.-, C2.-, C3.-, C4.2, C5.-, C6.2, C7.-, C8.-, CN1.1 (2), LED2.K (C), R2.1, R3.2, R7.1, R8.2, SV1.9, SV2.2, SV3.9, SV4.2, U1.2 (GND), U2.2 (VSS), U3.3 (GND), X1.4
unnamed: C2.+, D1.C, Q1.2 (S), S1.2
unnamed: R1.2, U2.1 (STAT)
unnamed: R4.2, S1.1 (O), U1.1 (IN)
unnamed: LED1.K (C), R1.1
unnamed: R3.1, U2.5 (PROG)
unnamed: R4.1, U1.3 (EN)
unnamed: LED2.A, R5.1
unnamed: C6.1, R6.1, R7.2, U3.1 (!SHDN)
unnamed: L1.1, U3.4 (LX)
unnamed: R8.1, R9.2, U3.6 (FB(!RST))
VBAT: C1.+, CN1.2 (1), Q1.3 (D), U2.3 (VBAT)

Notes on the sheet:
Original design: Hallmar Gauti Halldórsson
Battery charger
3.3V to 5V Buck Boost

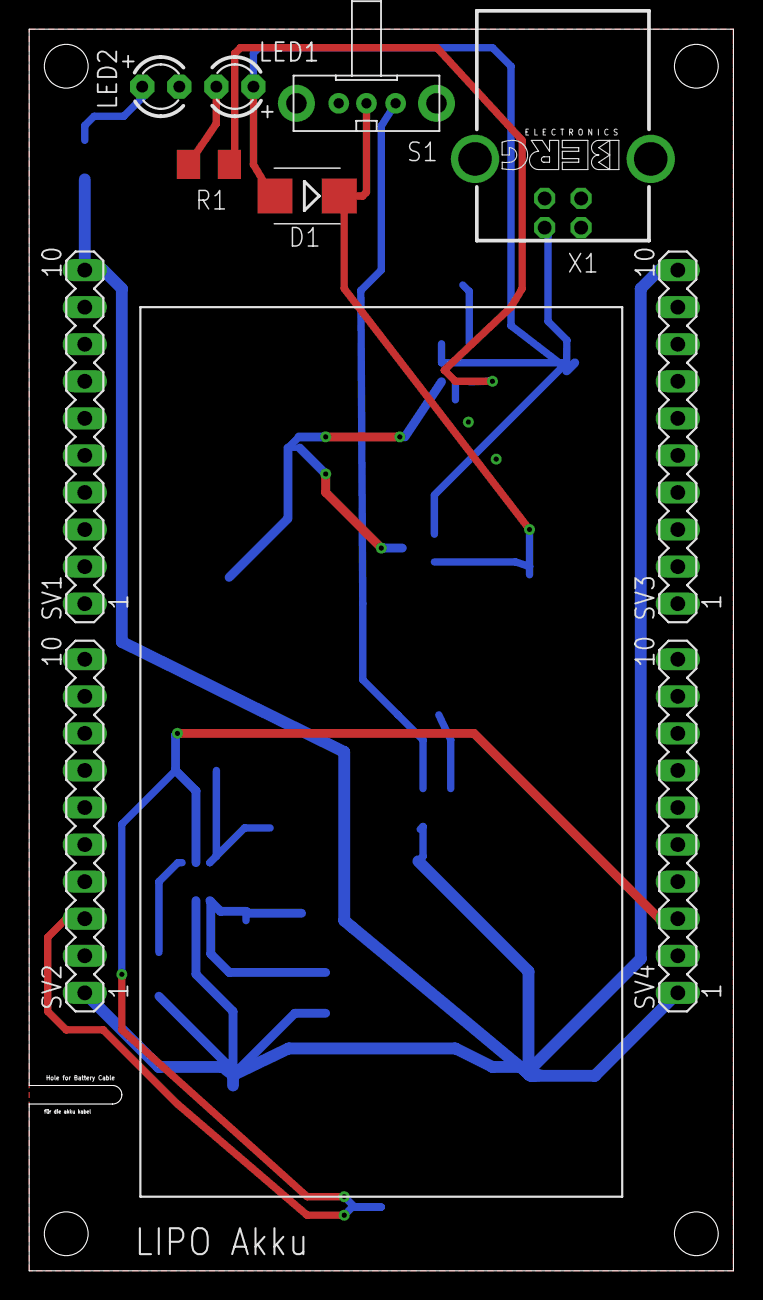
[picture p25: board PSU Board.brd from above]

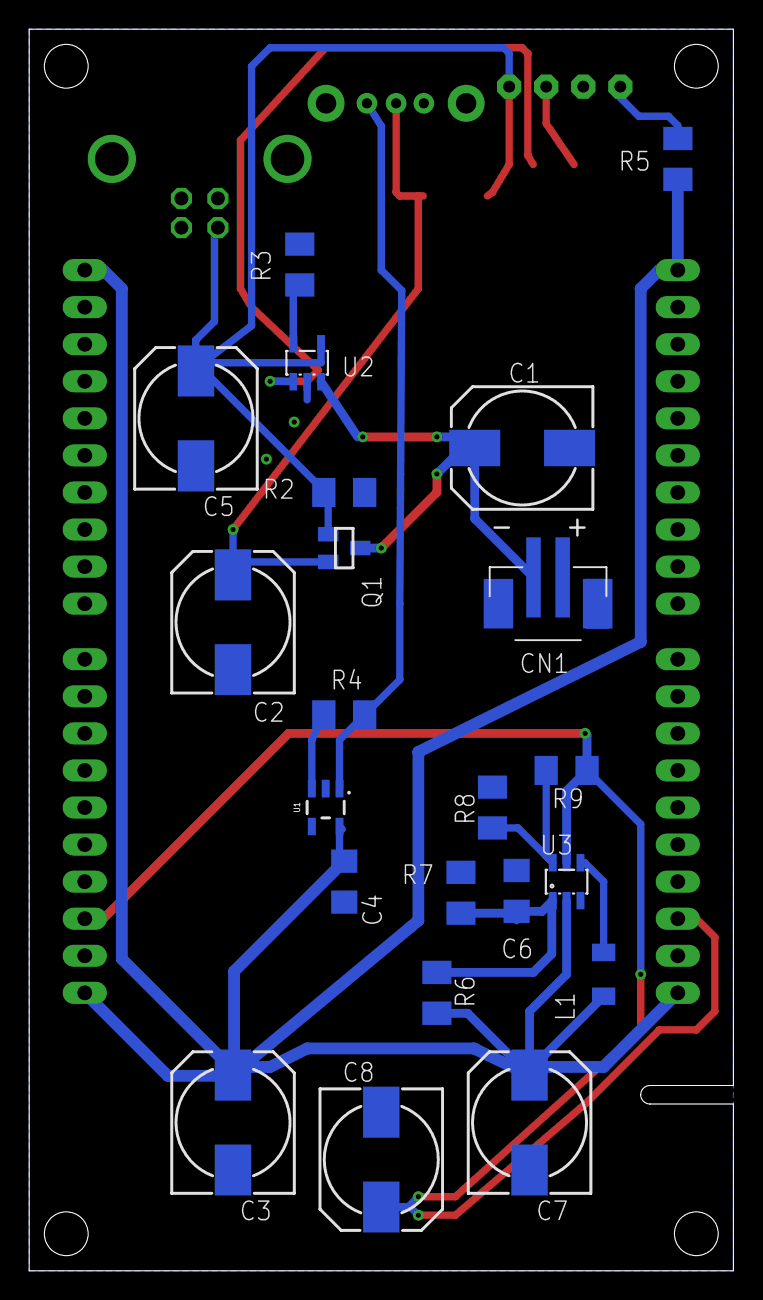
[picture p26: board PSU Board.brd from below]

Board: 2 copper layers, 48.3 x 85.1 mm, 32 parts (22 on the bottom side), 15 nets.

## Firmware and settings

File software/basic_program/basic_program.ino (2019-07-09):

#include <WiFi.h>
#include <WiFiClient.h>
#include <WiFiServer.h>
#include <WiFiUdp.h>
#include <WiFiAP.h>

#include <SPI.h>
#include <Wire.h>
#include <Adafruit_GFX.h>
#include <Adafruit_SSD1306.h>
#define Reset 14
Adafruit_SSD1306 display = Adafruit_SSD1306(128, 64, &Wire, Reset);

// OLED FeatherWing buttons map to different pins depending on board:
#define BUTTON_A 33
#define BUTTON_B 15
#define BUTTON_C 32
#define rota     12
#define rotb     27
#define rotpush  13

// Set these to your desired credentials.
const char* ssid = "ESP32";
const char* password = "password";
String ledstatus = "LED ON";
WiFiServer server(80);

void setup() {
  Serial.begin(115200);

  Serial.println("OLED FeatherWing test");
  // SSD1306_SWITCHCAPVCC = generate display voltage from 3.3V internally
  if (!display.begin(SSD1306_SWITCHCAPVCC, 0x3D)) {// Address 0x3D for 128x64
    Serial.println("error!!");
    for (;;);
  }


  Serial.println("OLED begun");

  // Show image buffer on the display hardware.
  // Since the buffer is intialized with an Adafruit splashscreen
  // internally, this will display the splashscreen.
  display.display();
  delay(1000);

  // Clear the buffer.
  display.clearDisplay();
  display.display();

  Serial.println("IO test");

  pinMode(BUTTON_A, INPUT);
  pinMode(BUTTON_B, INPUT);
  pinMode(BUTTON_C, INPUT);
  pinMode(rota, INPUT);
  pinMode(rotb, INPUT);
  pinMode(rotpush, INPUT);
  
  display.setTextSize(1);
  display.setTextColor(WHITE);
  display.setCursor(0,0);
    display.print("Hello!");
  display.display();
}
  void loop(){

  if(digitalRead(rotpush)) display.print("Rotary push");
  if(digitalRead(BUTTON_A)) display.print("A");
  if(digitalRead(BUTTON_B)) display.print("B");
  if(digitalRead(BUTTON_C)) display.print("C");
  display.display();
  delay(10);
  display.clearDisplay();
  display.setCursor(0,0);

  }

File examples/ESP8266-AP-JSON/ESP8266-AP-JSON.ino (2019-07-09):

/*
 * Copyright (c) 2015, Majenko Technologies
 * All rights reserved.
 * 
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
 * * Neither the name of Majenko Technologies nor the names of its
 *   contributors may be used to endorse or promote products derived from
 *   this software without specific prior written permission.
 * 
 * THIS SOFTWARE IS PROVIDED BY THE COPYRIGHT HOLDERS AND CONTRIBUTORS "AS IS" AND
 * ANY EXPRESS OR IMPLIED WARRANTIES, INCLUDING, BUT NOT LIMITED TO, THE IMPLIED
 * WARRANTIES OF MERCHANTABILITY AND FITNESS FOR A PARTICULAR PURPOSE ARE
 * DISCLAIMED. IN NO EVENT SHALL THE COPYRIGHT HOLDER OR CONTRIBUTORS BE LIABLE FOR
 * ANY DIRECT, INDIRECT, INCIDENTAL, SPECIAL, EXEMPLARY, OR CONSEQUENTIAL DAMAGES
 * (INCLUDING, BUT NOT LIMITED TO, PROCUREMENT OF SUBSTITUTE GOODS OR SERVICES;
 * LOSS OF USE, DATA, OR PROFITS; OR BUSINESS INTERRUPTION) HOWEVER CAUSED AND ON
 * ANY THEORY OF LIABILITY, WHETHER IN CONTRACT, STRICT LIABILITY, OR TORT
 * (INCLUDING NEGLIGENCE OR OTHERWISE) ARISING IN ANY WAY OUT OF THE USE OF THIS
 * SOFTWARE, EVEN IF ADVISED OF THE POSSIBILITY OF SUCH DAMAGE.
 */

/* Create a WiFi access point and provide a web server on it. */

#include <ESP8266WiFi.h>
#include <WiFiClient.h> 
#include <ESP8266WebServer.h> 
int LDRPin = A0;
int LDRReading = 0; 
/* Set these to your desired credentials. */
const char *ssid = "LightLevelESP";
const char *password = "";
int milisInterval = 2000;
int count = 0;
ESP8266WebServer server(80);

/* Just a little test message.  Go to http://192.168.4.1 in a web browser
 * connected to this access point to see it.
 */
void handleRoot() {
LDRReading = analogRead(LDRPin);
String html ="<!DOCTYPE html> <html> <head><meta name=\"viewport\" content=\"width=device-width, minimumscale=1.0, maximum-scale=1.0, initial-scale=1\" /><style> body {text-align: center; max-width: 400px; margin: 10px auto;} #updateView { max-width: 400px; display: none; margin-top: 30px; } #dataVals { max-width: 400px; display: block; margin-top: 30px; } .convertButton { clear: both; position:relative; margin-top: 30px; -moz-box-shadow: 0px 1px 0px 0px #fff6af; -webkit-box-shadow: 0px 1px 0px 0px #fff6af; box-shadow: 0px 1px 0px 0px #fff6af; background:-webkit-gradient(linear, left top, left bottom, color-stop(0.05, #ffec64), color-stop(1, #ffab23)); background:-moz-linear-gradient(top, #ffec64 5%, #ffab23 100%); background:-webkit-linear-gradient(top, #ffec64 5%, #ffab23 100%); background:-o-linear-gradient(top, #ffec64 5%, #ffab23 100%); background:-ms-linear-gradient(top, #ffec64 5%, #ffab23 100%); background:linear-gradient(to bottom, #ffec64 5%, #ffab23 100%); filter:progid:DXImageTransform.Microsoft.gradient(startColorstr='#ffec64', endColorstr='#ffab23',GradientType=0); background-color:#ffec64; -moz-border-radius:6px; -webkit-border-radius:6px; border-radius:6px; border:1px solid #ffaa22; display:inline-block; cursor:pointer; color:#333333; font-family:Arial; font-size:21px; padding:14px 69px; text-decoration:none; text-shadow:0px 1px 0px #ffee66; } .convertButton:hover { background:-webkit-gradient(linear, left top, left bottom, color-stop(0.05, #ffab23), color-stop(1, #ffec64)); background:-moz-linear-gradient(top, #ffab23 5%, #ffec64 100%); background:-webkit-linear-gradient(top, #ffab23 5%, #ffec64 100%); background:-o-linear-gradient(top, #ffab23 5%, #ffec64 100%); background:-ms-linear-gradient(top, #ffab23 5%, #ffec64 100%); background:linear-gradient(to bottom, #ffab23 5%, #ffec64 100%); filter:progid:DXImageTransform.Microsoft.gradient(startColorstr='#ffab23', endColorstr='#ffec64',GradientType=0); background-color:#ffab23; } .convertButton:active { position:relative; top:1px; }</style></head> <body> <a onClick=\"changeView()\" class=\"convertButton\" id=\"viewButton\">Update Rate</a> <div id=\"dataVals\"> <h1>Light Level</h1> <div id=\"light\">";
html += LDRReading;
html +="</div><h1>Count Number</h1><div id=\"countNum\">";
html += count;
html +="</div> </div> <div id=\"updateView\"> <label for=\"fader\">Update rate in Milliseconds</label><br /> <input type=\"range\" style=\"width: 300px\" min=\"200\" max=\"5000\" value=\"2000\" id=\"fader\" step=\"1\" oninput=\"outputUpdate(value)\"> <output for=\"fader\" id=\"volume\">2000</output></div> <script> var changed = false; function changeView(){ if(changed == false){ document.getElementById('updateView').style.display = 'block'; document.getElementById('dataVals').style.display = 'none'; document.getElementById('viewButton').innerHTML = \"Show Data\"; changed = true; } else{ document.getElementById('updateView').style.display = 'none'; document.getElementById('dataVals').style.display = 'block'; document.getElementById('viewButton').innerHTML = \"Update Rate\"; changed = false; } } function loadDoc() { var xhttp = new XMLHttpRequest(); xhttp.onreadystatechange = function() { if (this.readyState == 4 && this.status == 200) { var obj = JSON.parse(this.responseText); document.getElementById(\"light\").innerHTML = obj.data[0].dataValue; document.getElementById(\"countNum\").innerHTML = obj.data[1].dataValue; } }; xhttp.open(\"GET\", \"/data\", true); xhttp.send(); } var timedEvent = setInterval(function(){ loadDoc(); }, 2000); function outputUpdate(vol) { clearInterval(timedEvent); timedEvent = setInterval(function(){ loadDoc(); }, vol); document.querySelector('#volume').value = vol; delayVal = vol; } </script> </body> </html>";

	server.send(200, "text/html", html);
}

void getData() {   
   //This is a JSON formatted string that will be served. You can change the values to whatever like.
   // {"data":[{"dataValue":"1024"},{"dataValue":"23"}]} This is essentially what is will output you can add more if you like
  LDRReading = analogRead(LDRPin);
  String text2 = "{\"data\":[";
  text2 += "{\"dataValue\":\"";
  text2 += LDRReading;
  text2 += "\"},";
  text2 += "{\"dataValue\":\"";
  text2 += count;
  text2 += "\"}";
  text2 += "]}";
  server.send(200, "text/html", text2);
  count++;
}

void setup() {
	delay(1000);
	Serial.begin(115200);
	Serial.println();
	Serial.print("Configuring access point...");
	/* You can remove the password parameter if you want the AP to be open. */
	WiFi.softAP(ssid, password);

	IPAddress myIP = WiFi.softAPIP();
	Serial.print("AP IP address: ");
	Serial.println(myIP);
	server.on("/", handleRoot);
 server.on("/data", getData);
	server.begin();
	Serial.println("HTTP server started");
}

void loop() {
	server.handleClient();
}

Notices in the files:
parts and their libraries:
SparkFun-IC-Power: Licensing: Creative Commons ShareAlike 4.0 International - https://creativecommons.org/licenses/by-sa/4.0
